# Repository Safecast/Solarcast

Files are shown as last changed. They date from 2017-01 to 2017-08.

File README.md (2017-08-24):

# Solarcast
Safecast Solarcast sensor device is designed to operate off-grid and sense environmental parameters. It consists of 5 key modules designed for maximal reuse.

## Modular design
 1. [Air sensor module](/air-module)
 2. [Geiger sensor module](/geiger-module)
 3. [Battery power module](/battery-module)
 4. [Communications module](/communications-module)
 5. [Gateway module](/gateway-module)

In an optimal design all modules have their own BLE processor and can be directly combined between each other, initial design is however only partially modular.

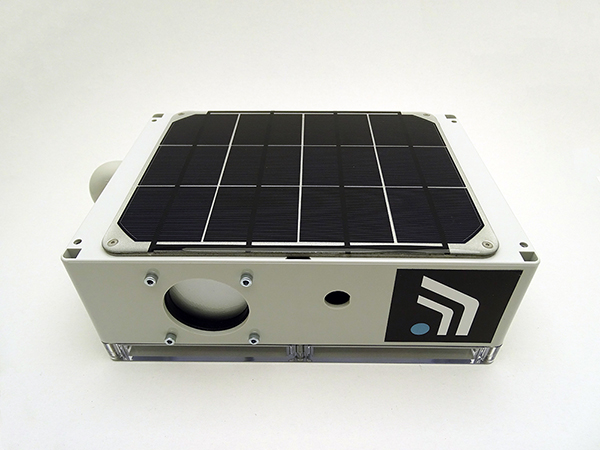
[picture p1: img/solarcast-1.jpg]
Solarcast-1

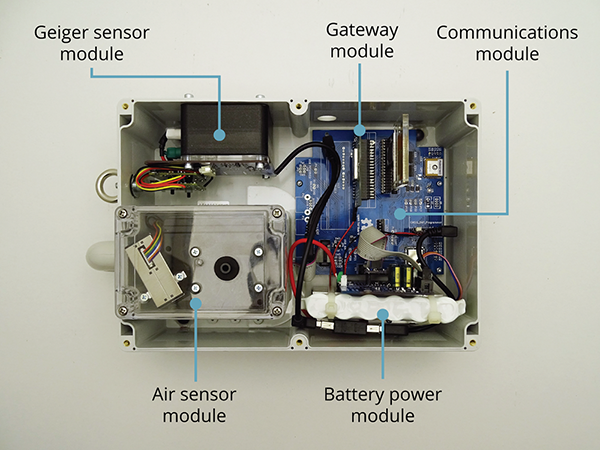
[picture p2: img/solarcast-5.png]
Solarcast-2


## Design parameters
The PCBs have to be designed in KiCad package.

---

#### License

Open data generated by Safecast is licensed under [CC0](https://creativecommons.org/publicdomain/zero/1.0/legalcode).

Hardware, Software, and Firmware licenses TBD.

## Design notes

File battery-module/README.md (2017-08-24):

### IoT power module description

This repository contains the design parameters and implementation details of the IoT battery pack originally developed for [Safecst Solarcast](https://github.com/IRNAS/Solarcast) sensor device.

## GENERAL DESCRIPTION

IoT power module is powered from single lithium-ion cells (2/4/6 cells in parallel) and provides 3V3 and 5V stabilized output as well as battery output. All inputs can be turned off to avoid power consumption, however by default 3V3 output is always active (see later). Both switcher chips are buck-boost topology and operate with very low current when idle (< 100 uA)

The module itself is equipped with switcher battery charger, where charging current can be externally programmed using resistors (R56, R58) or programming through I2C interface is also possible. An add-on module enables charging from external solar panel or other input, where integrated electronics adjusts the current in a way, that current is lowered when Uin_min threshold is achieved (currently at 4V5). Other option is charging through microUSB port with 5 VDC.

The module can be equipped with Nordic nRF51822 microprocessor (M0 with BLE), that can be used to monitor and control charging process. Additionally, fuel gauge MAX17201 chip is integrated, which can monitor all battery parameters such as voltage, current, temperature, calculates state-of-charge (SOC), state-of-health (SOH) and many other parameters.

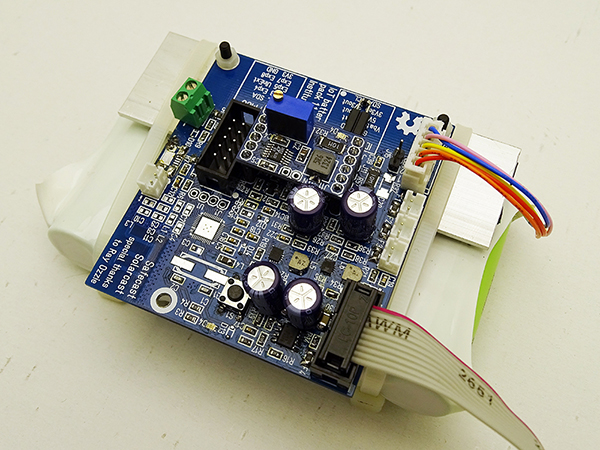
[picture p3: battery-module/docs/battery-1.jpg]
Battery-module


## BASIC BOARD OVERVIEW

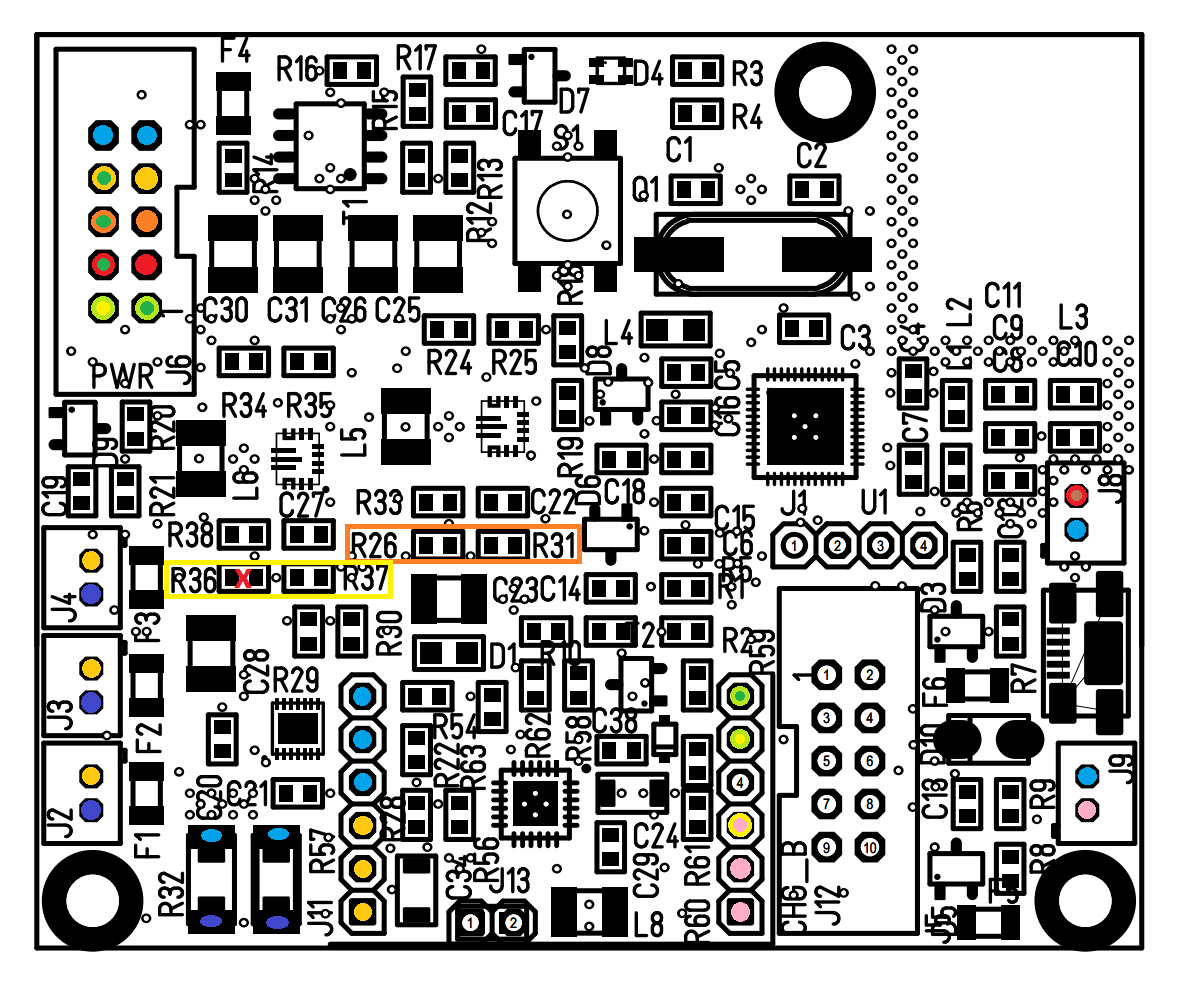
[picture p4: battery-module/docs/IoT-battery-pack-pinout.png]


### J2, J3, J4 (bottom left): Battery connectors, 3 pcs (JST 2-pole)
Connect to lithium battery pack. 3 packs can be connected simoultanously. Each branch is protected using 5A SMD fuse.
IMPORTANT!
 1. Always connect only battery packs with similar voltage/charging state. Connecting i.e. empty and full battery pack will drain huge current from full battery and burn fuse as well as damage to the batteries can be done!
 1. GND of the cells and GND of the system is not the same as there is a shunt resistor (R32, R57) in line between Cell_gnd and System_gnd.

### J6 (top left): PWR connector (IDC10):

diagram

1. - I2C SCL (3V3)
2. - I2C SDA (3V3)
3. - 5V0 output*
4. - 5V0_enable pin*
5. - 3V3 output (always on by default**)
6. - 3V3_enable pin (not used by default**)
7. - Vbat output (same logic as 5V0 output*)
8. - Vbat_enable pin
9. - GND
10. - GND

*By default, 5V0 output is disabled and can only be enabled if pulling 5V0 enable pin high. In case, that constant voltage is required on the 5V0 output, R36 must be populated. This will create resistor divider to define voltage level, when power will disable due to under-voltage condition.*

*By default, 3V3 output is always active and is disabled only, when under-voltage condition occurs (set to approx. 3V using R26 and R31). If you want to enable 3V3_enable control, R26 must be removed.*

### J8 + micro USB (middle right): +5 VDC power supply
Input for stabilized 5V power supply. Circuit around T2 serves adjusting charging current in a way, that if +5V power line drops, charging current is gradually reduced from approx. 1,8 A to 0,5 A at approx. 4,5 V.

### J9 (bottom right): external charging voltage (JST 2-pole)

Input for solar panel or other power source (voltage depends on a module installed).

### J11, J12 (bottom middle): connectors for add-on charging board

Module has prepared option to install add-on module with additional charger; this way i.e. MPPT module or wide-range DCDC charger can be installed and replaced if required. There are also I2C pins present at J12 as well as one additional pin from MCU as well as Usense pin, which regulates charging current for the on-board charging chip.

### J13 (bottom middle): connector for battery NTC thermistor (10k)

NTC thermistor must be thermally attached to the battery cell.

# IoT battery pack requirements
IoT battery pack is designed to provide power in various sensing applications, being able to deliver sufficient power for a wide range of sensors for short periods of time and have a long standby operation time between them. BLE interface allows users to configure it as well as provide a communication channel to talk to other sensors in the vicinity.

 * Capacity: 1P-6P Li-Po 18650 (3600mAh - 20000mAh)
  * Batteries connected in 3 branches of two, each branch fuse protected
  * User can connect 1-6 cells in parallel. For safety, no more then two can be directly connected in parallel, thus the 6 cells in parallel are split in 3 pairs of 2 cells in parallel, the sets connected together each via its own fuse.
  * Connector for cells: 2.54 JST (not mounted)
 * Input: 2A at 5V, input range 3-6V
  * DC jack input for solar cell, no diode used
  * Micro USB input for wall-socket (Additionally 2 pads for connections)
  * USB input must disconnect the solar cell and prevent discharge into it, can be done with a relay. Relay powered from USB socket via diode in a way, that NC is solar cell and NO is external 5 V input.
  * Current shall be adjustable from MCU (PWM?) and via trimmer in a way, that voltage is defined, where current is lowered (i.e. at 4V5 system goes to CV mode on input). Dynamic adjustment of charge current, such that the input voltage does not drop below 4.5V or other configurable level if possible. This prevents overloading of the supply, for example when solar cell is connected holds it reasonably close to maximum power output voltage. If possible the voltage level should be software controlled via BLE.

 * Output: 2A at 5V, 1A at 3.3V, direct battery voltage output
  * 5V - High-side switch or DC-DC module disable + fuse
  * 3.3V - High-side switch or DC-DC module disable + fuse
  * battery voltage - High-side switch and a fuse
  * Out connectors 2.54mm header/JST terminal
 * BLE processor (preferred Nordic nRF51822) on board implementing the following features in software:
  * battery voltage and current measurement. All voltages (inputs, outputs), current is measured through Fuel gauge chip via I2C
  * configurable thermal protection/shutdown via fuel gauge I2C
  * configurable battery charge voltage (over-voltage protection) via fuel gauge I2C
  * configurable battery discharge voltage (under-voltage protection) via fuel gauge I2C
  * I2C interface (nRF51822 SDA 10, SCL 8)
  * Enable/disable outputs as defined above
  * Expose remaining GPIO, about 8-10 are sufficient (to 10 pin header vcc/+3v3+8gpios)
  * RG(B) LED from MCU, software controlled and can be disabled fully
  * Standard Cortex programming connector
  * [Grove I2C connector](http://wiki.seeed.cc/Grove-I2C_Hub/)
 * Simultaneous charging and discharging
 * Low quiescent current - standby mode with 3.3V branch active no more then 100uA battery discharge current
 * Input DC-DC with current limiter
  * Dynamic adjustment of charge current, such that the input voltage does not drop below 4.5V or other configurable level if possible. This prevents overloading of the supply, for example when solar cell is connected holds it reasonably close to maximum power output voltage. If possible the voltage level should be software controlled via BLE.

 * Target production cost ~15EUR@1k
  * Batteries excluded
 * Prototyping process: 10 units for testing in first batch, 30 units in second batch

## Diagram
Diagram is made in http://draw.io

diagram

---

#### License

All our projects are as usefully open-source as possible.

Hardware including documentation is licensed under [CERN OHL v.1.2. license](http://www.ohwr.org/licenses/cern-ohl/v1.2)

Firmware and software originating from the project is licensed under [GNU GENERAL PUBLIC LICENSE v3](http://www.gnu.org/licenses/gpl-3.0.en.html).

Open data generated by our projects is licensed under [CC0](https://creativecommons.org/publicdomain/zero/1.0/legalcode).

All our websites and additional documentation are licensed under [Creative Commons Attribution-ShareAlike 4 .0 Unported License] (https://creativecommons.org/licenses/by-sa/4.0/legalcode).

What this means is that you can use hardware, firmware, software and documentation without paying a royalty and knowing that you'll be able to use your version forever. You are also free to make changes but if you share these changes then you have to do so on the same conditions that you enjoy.

Koruza, GoodEnoughCNC and IRNAS are all names and marks of Institut IRNAS Rače. 
You may use these names and terms only to attribute the appropriate entity as required by the Open Licences referred to above. You may not use them in any other way and in particular you may not use them to imply endorsement or authorization of any hardware that you design, make or sell.

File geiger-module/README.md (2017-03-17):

# Geiger module for Solarcast
Geiger module is a standalone sensor unit that is a part of the Solarcast assembly and houses two Geiger tubes and a temperature and humidity sensor along with an optional BLE processor module.

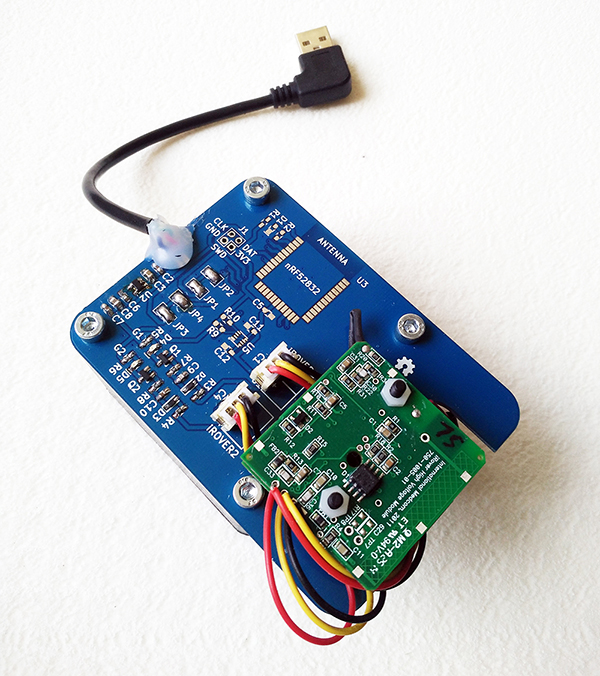
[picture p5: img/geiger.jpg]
Geiger


## Design specification
* BLE module NRF [nRF52832 ANT](https://www.tindie.com/products/hnhoan/nrf52832-ant-bluetooth-le-arm-cortex-m4f-30-io/)
* Geiger pancake sensor (may be a stack of two)
* Geiger gamma compensated tube sensor
* Temperature and humidity sensor BME280 sensor (I2C SDO high 0x77)
* 5V power supply via USB connector (no USB data)
* Outdoor enclosure [PNR-2603](http://eu.mouser.com/ProductDetail/Bud-Industries/PNR-2603/?qs=sGAEpiMZZMsrGrAVj6eTvTO11XxqWC53gJbMy7TDIp4%3d)
* BLE module LED-RED

## Extended details
* Waterproof [USB connector](http://eu.mouser.com/ProductDetail/Conxall-Switchcraft/DCP-USBCB-SC/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
) (data lines carry SWDIO & SWCLK signals or Geiger 1 and Geiger 2 output signals, configuration depending via jumper)
* Internal 3V3 regulator
* 2pcs iRover HV board, stacked

## Connection details
The devices have the following connection details:

*  nRF52832 module
 * Pin 3: P0.23	LED-RED
 * Pin 5: P0.25	TWI-SDA
 * Pin 6: P0.26 TWI-SCL
 * Pin 7: P0.28	GEIGER0
 * Pin 8: P0.29 GEIGER1
 * Pin 18: 3.3V
 * Pin 19: GND
 * Pin 21: SWCLK/TCK
 * Pin 22: SWDIO/TMS

## Board layout
The PCB board has the two tubes mounted on one side with cables passing though and being connected directly to iRover boards on the other side. These boards are placed one next to the other. BLE module is placed somewhere along the edge, USB connector is on the short edge opposite to the side where the cutout for cables is.

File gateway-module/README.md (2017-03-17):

# Gateway module for Solarcast
Gateway module implements LORA communication for two purposes, installing it inside the Solarcast device as a LORA communications module as well as attachign it to a RaspberryPi to act as a gateway.

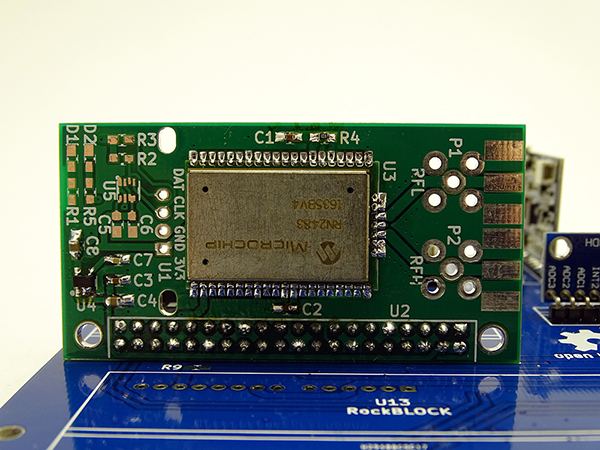
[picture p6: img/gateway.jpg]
Gateway


## Design specification
* LORA module [Microchip RN2483](http://www.microchip.com/wwwproducts/en/RN2483) for EU band, alternatively RN2903 for US band
* SMA connector for 434MHz (RF layout guide on [datasheet page 10](http://ww1.microchip.com/downloads/en/DeviceDoc/50002346B.pdf))
* SMA connector for 868MHz (RF layout guide on [datasheet page 10](http://ww1.microchip.com/downloads/en/DeviceDoc/50002346B.pdf))
* SSD1306 i2c display (optional)
* 5V power supply and an on board 3V3 regulator, such that it can eb used directly from 3V3 as well\
* Status LED for each RPi and LORA module
* Temperature and humidity sensor BME260 sensor (I2C SDO high 0x77)

## Connection details
The devices have the following connection details:

*  RN2483 module
 * Connect UART (RX,TX,RTS,CTS)
 * LED on GPIO
*  RaspberryPi
  * Connect UART (RX,TX,RTS,CTS)
  * Connect I2C
  * Connect an LED to GPIO

## Board layout
The PCB board is a RaspberryPi shield.

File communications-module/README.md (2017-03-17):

# Communications module for Solarcast
Communications module operates as the main module for the complete Solarcast assembly and is primarily a BLE device with other comms modules being plugged in.

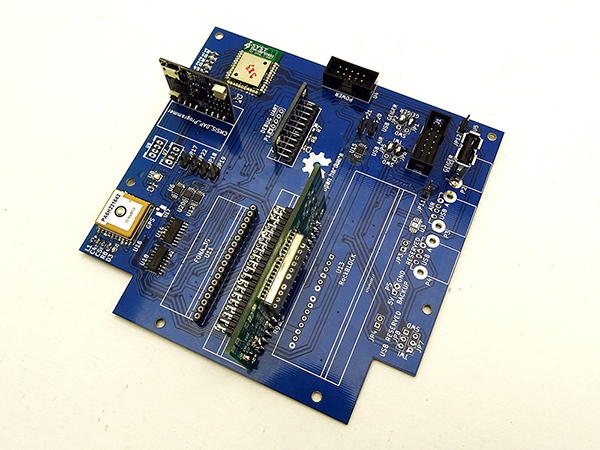
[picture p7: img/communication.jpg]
Communications-module


## Design specification
* NRF module [nRF52832 ANT](https://www.tindie.com/products/hnhoan/nrf52832-ant-bluetooth-le-arm-cortex-m4f-30-io/)
* Programmer [CMSIS-DAP](https://www.tindie.com/products/hnhoan/cmsis-dap-arm-debug-jtagswd-module-drag-and-drop/)
* [GPS module](https://www.adafruit.com/products/790)
* [Adafruit FONA 3G module](https://www.adafruit.com/products/2691) (Note version difference between USA and EU)
* GSM antenna [FXUB66.07.0150C](http://www.mouser.com/ProductDetail/Taoglas/FXUB66070150C/?qs=L8NdhHdZHXxzH3hw8Na69A%3D%3D)
* LORA antenna [FXUB66.01.0150C](http://www.mouser.com/ProductDetail/Taoglas/FXUB66010150C/?qs=sGAEpiMZZMuBTKBKvsBmlEt2wojY8dgW39nSVW3ZfN0%3d)
* BME280 sensor (SDO low 0x76)
* Add accelerometer [LIS3DSH](https://www.adafruit.com/products/2809) footprint for the ic and pins for breakout
* UART MUX SN74LV4052AD SOIC-16
* USB connector to outside world http://eu.mouser.com/ProductDetail/Conxall-Switchcraft/DCP-USBCB-SC/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
* Case: PN-1335
* Add a GPIO expansion port for later work (UART for Air can be on it and I2C and SPI)
* Three internal USB connectors, not carrying USB data
 * USB0 - data pins select between I2C and programming pins
 * USB1 - data pins select between I2C and programming pins
 * USB2 - data pins select between GEIGER0/GEIGER1 and programming pins
* Connector for power module
* 2 groove expansion ports
* External power switch mounted on the box.

## Power supply configuration
Solar operation of the device and minimal power consumption in the standby state govern the design requirements.

Power flow: Solar cell-> Power module (built-in regulators) -> Comms module -> Power switch and fan out to:
* Switch high-side 5V - USB0 for Air module - ENABLE-AIR - 250mA peak - [TPS2034D](http://www.ti.com/product/TPS2034D?keyMatch=TPS2034D&tisearch=Search-EN-Everything) regulated from battery pack
* Switch high-side 5V - USB1 for Geiger module - ENABLE-GEIG - 50mA peak - [TPS2034D](http://www.ti.com/product/TPS2034D?keyMatch=TPS2034D&tisearch=Search-EN-Everything) regulated from battery pack
* Switch high-side 5V - USB2 -reserve- 1A peak [TPS2034D](http://www.ti.com/product/TPS2034D?keyMatch=TPS2034D&tisearch=Search-EN-Everything)
* Switch high-side 5V - backup - 1A peak [TPS2034D](http://www.ti.com/product/TPS2034D?keyMatch=TPS2034D&tisearch=Search-EN-Everything)

Power switch disconnects power between power module and comms module.

Add headers for mosfet bypass for current consumption measurement and jumpers prior to voltage regulators.

## Board layout
The board is designed as a main board with all other modules connecting to it.

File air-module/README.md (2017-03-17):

# Air module for Solarcast
Air module is a standalone sensor unit that is a part of the Solarcast assembly and houses two particle sensors and a temperature and humidity sensor along with an optional BLE processor module.

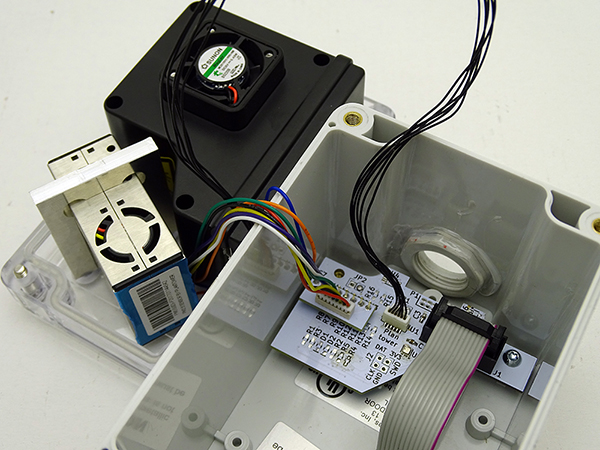
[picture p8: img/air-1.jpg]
Air-module


## Design specification
* BLE module NRF [nRF52832 ANT](https://www.tindie.com/products/hnhoan/nrf52832-ant-bluetooth-le-arm-cortex-m4f-30-io/)
* Particle sensor [Alphasense OPC-N2](http://www.alphasense.com/index.php/products/optical-particle-counter/) (SPI)
* Particle sensor [PM2.5 PMS 5003](http://www.plantower.com/en/content/?108.html) (UART)
* Temperature and humidity sensor BME280 sensor (I2C SDO high 0x77)
* 5V power supply via USB connector (no USB data)
* Outdoor enclosure [PNR-2603](http://eu.mouser.com/ProductDetail/Bud-Industries/PNR-2603/?qs=sGAEpiMZZMsrGrAVj6eTvTO11XxqWC53gJbMy7TDIp4%3d)
* Dual channel high side Switch high-side switch [TPS2034D](http://www.ti.com/product/TPS2034D?keyMatch=TPS2034D&tisearch=Search-EN-Everything) each output for one AIR sensor, with bypass header jumpers.

## Extended details
* Waterproof [USB connector](http://eu.mouser.com/ProductDetail/Conxall-Switchcraft/DCP-USBCB-SC/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
) (data lines carry SWDIO & SWCLK signals)
* Internal 3V3 regulator
* Expansion connector 2x6 (IDC connector) with SPI, I2C and UART

## Connection details
The devices have the following connection details:

* Alphasense (leftmost wire on connector with wire crimp contacts facing up going away from you) Connector: Molex 'Pico Clasp' 6 way Housing, Part Number 501330-0600
 1. 5V
 2. SPI-SCLK
 3. SPI-MISO
 4. SPI-MOSI
 5. SPI-CS
 6. GND

* Plantower, no connector, solder wires
  1. 5V
  2. GND
  3. N/C
  4. RX (optional SCL) (add 0 ohm resistors to select between uart and i2c pins)
  5. TX (optional SDA) (add 0 ohm resistors to select between uart and i2c pins)
  6. N/C
  7. comm config (add solder jumpers for pull up/down)
  8. comm config (add solder jumpers for pull up/down)

*  nRF52832 module
 * Pin 3: P0.23	LED-RED
 * Pin 5: P0.25	TWI-SDA
 * Pin 6: P0.26 TWI-SCL
 * Pin 7: P0.27 UMUX-INH
 * Pin 18: 3.3V
 * Pin 19: GND
 * Pin 20: P0.07 TX
 * Pin 21: SWCLK/TCK
 * Pin 22: SWDIO/TMS
 * Pin 23: P0.08 RX
 * Pin 28: P0.03 SPI-MOSI
 * Pin 29: P0.04 SPI-MISO
 * Pin 30: P0.05 SPI-CS
 * Pin 31: P0.06 SPI-SCLK

 ## Board layout
 The PCB board has a connector of each particle sensor, BLE module on the short board edge and the USB connector on the edge between two rounded corners.

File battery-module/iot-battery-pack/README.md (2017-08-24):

# IoT battery pack hardware
Last revision is v.1.2 available in this repository, while v.1.1 version can with manual fixes be brought to v.1.2.

## IoT power supply errata HW REV affected: v.1.1

- Missing 10 uF 10V X7R 0805 capacitors at input and output of IC1 and IC2 (fixed at v.1.2)
- Check/enlarge track for VBAT to BAT FET, optimize vias (too much current drop) (fixed at v.1.2)
- Modify resistor divider on MPPT charger to set charging voltage to 4,10 V (4,0 at v.1.1)

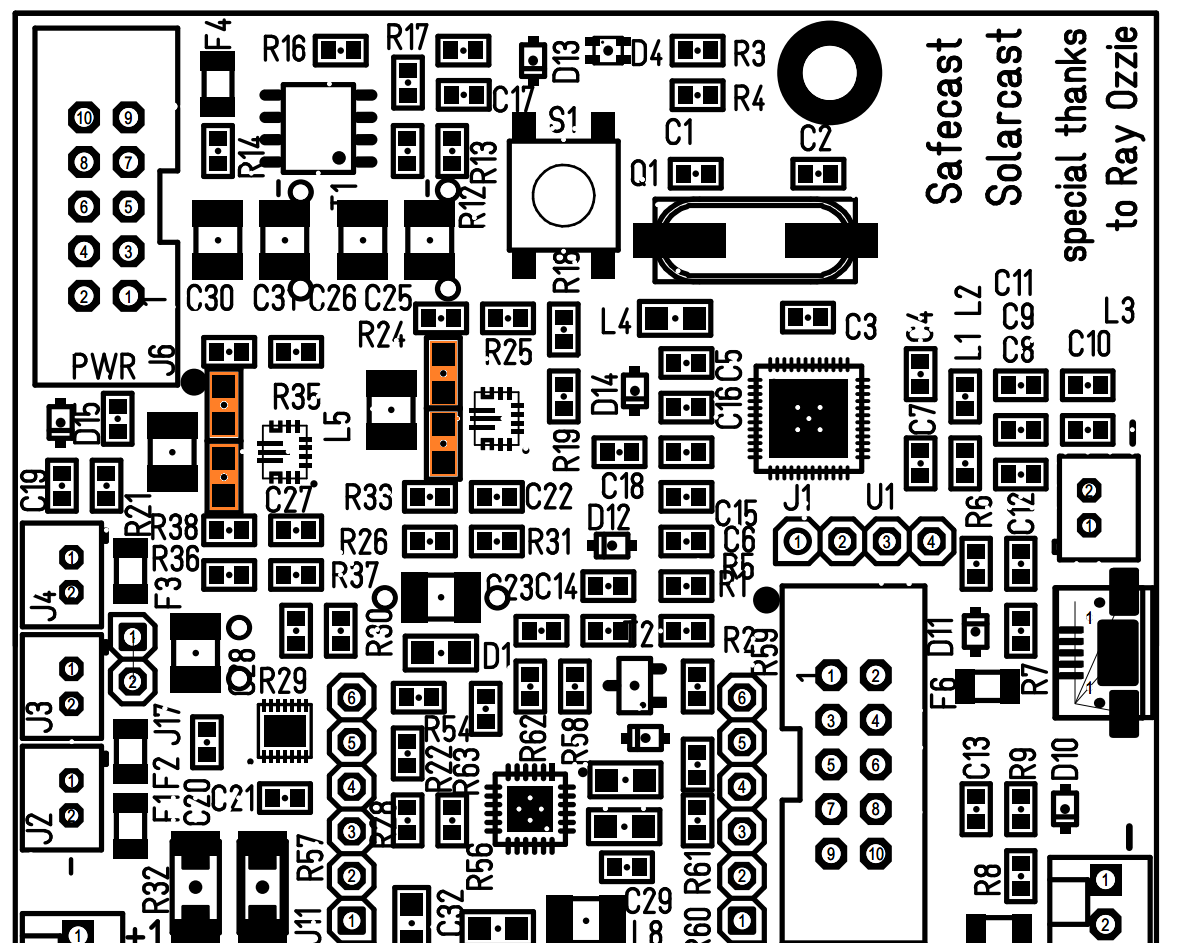
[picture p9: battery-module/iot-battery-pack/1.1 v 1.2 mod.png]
diagram


## Fuses
 * F1 - Battery fuse 3A
 * F2 - Battery fuse 3A
 * F3 - Battery fuse 3A
 * F4 - Battery output fuse 3A
 * F5 - Solar input fuse 3A
 * F6 - USB input fuse 3A

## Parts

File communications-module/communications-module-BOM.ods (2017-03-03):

Designator | Package | Quantity | Description | Supplier Link
C1,C2,C3,C5 | 0603_HandSoldering | 4 | 100nF
C4 | 0603_HandSoldering | 1 | 1uF
D1,D2,D3 | LED_0603_HandSoldering | 3 | LED
J1 | IDC12_connector | 1 | IDC12
JP3,JP4,JP11,JP12,JP17,JP18,JP19,JP20,JP21,JP22 | Socket_Strip_Straight_1x02_Pitch2.54mm | 10 | Jumper2
L1 | 0603_HandSoldering | 1 | Ferrite bead | http://si.farnell.com/murata/blm18ag221sn1d/ferrite-bead-0-25ohm-500ma-0603/dp/1515674
P2,P3,P4 | USB_A_receptacle | 3 | USB_A | http://si.farnell.com/te-connectivity-amp/292303-1/usb-2-0-type-a-plug-cable/dp/1076663
P5 | Socket_Strip_Straight_1x02_Pitch2.54mm | 1 | BACKUP
R1,R2,R8 | 0603_HandSoldering | 3 | 1K
R3,R4,R5,R9 | 0603_HandSoldering | 4 | 10K
R6,R7 | 0603_HandSoldering | 2 | 0R
U1 | nRF52832-SMD | 1 | nRF52832 | https://www.tindie.com/products/hnhoan/nrf52832-ant-bluetooth-le-arm-cortex-m4f-30-io/
U2 | CMSIS_DAP_Breakout_Vertical | 1 | CMSIS_DAP_Programmer | https://www.seeedstudio.com/Seeed-Tiny-BLE-BLE-%2B-6DOF-Mbed-Platform-p-2268.html
U3,U5,U6,U12,U15,U20 | 8-Pin MSOP | 6 | TPS2066 | http://si.farnell.com/texas-instruments/tps2066dgn/power-load-switch-high-side-msop/dp/2323772
U4 | IDC10_connector | 1 | PWR_CONN
U7,U9 | Seeed Studio DIP Grove 4P-2_0 | 2 | I2C_connector | https://www.seeedstudio.com/Grove---Universal-4-pin-connector-p-789.html
U8 | 8-Pin LGA | 1 | BME280 | http://eu.mouser.com/ProductDetail/Bosch-Sensortec/BME280/
U10 | LIS3DH_breakout_vertical | 1 | LIS3DH_breakout | http://www.dx.com/p/cjmcu-lis3dh-3-axis-acceleration-module-alternative-adxl345-441837#.WKMPqfLwT2Y
U11 | FONA_3G_vertical | 1 | FONA_3G | https://learn.adafruit.com/adafruit-fona-3g-cellular-gps-breakout/overview
U13 | RockBlock_vertical | 1 | RockBLOCK | http://www.rock7mobile.com/products-rockblock
U14,U18 | SOIC-16 | 2 | SN74LV4052AD | http://si.farnell.com/texas-instruments/sn74lv4052ad/logic-mux-demux-4ch-analog-16soic/dp/1740190?aa=true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
U16 | FGPMMOPA6H | 1 | FGPMMOPA6H GPS | https://www.adafruit.com/product/790
U17 | U.FL-R-SMT | 1 | uFL_connector | http://si.farnell.com/hirose-hrs/u-fl-r-smt-1-10/rf-coaxial-u-fl-straight-jack/dp/1688077
U19 | Solarcast_Gateway_Module_Vertical | 1 | Gateway Module LORA
JP1,JP2,JP5,JP6,JP7,JP8 | Socket_Strip_Straight_1x03_Pitch2.54mm | 6 | Jumper3

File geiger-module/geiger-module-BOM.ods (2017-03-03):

Designator | Package | Quantity | Description | Supplier Link
J1 | Socket_Strip_Straight_2x02 | 1 | ARM_SWD_SMALL
U5 | 8-Pin LGA | 1 | BME280 | http://www.digikey.si/product-detail/en/bosch-sensortec/BME280/828-1063-1-ND/6136314
U4,U1 | JST B3B-PH-SM4-TB | 2 | iRover | http://si.farnell.com/jst-japan-solderless-terminals/b3b-ph-sm4-tb-lf-sn/connector-header-smt-2mm-3way/dp/9492542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
U3 | nRF52832-SMD | 1 | nRF52832 | https://www.tindie.com/products/hnhoan/nrf52832-ant-bluetooth-le-arm-cortex-m4f-30-io/
U2 | 5-Pin SOT23 | 1 | TPS79133 | http://si.farnell.com/texas-instruments/tps79133dbvt/ic-v-reg-ldo-0-1a-3-3v-smd-79133/dp/8461767
R10,R9,R1 | 0603_HandSoldering | 3 | 10K
R8,R7 | 0603_HandSoldering | 2 | 100K
R6,R5,R2 | 0603_HandSoldering | 3 | 100R
R4,R3 | 0603_HandSoldering | 2 | 1K
Q2,Q1 | 3-Pin SOT23 | 2 | BC847C | http://si.farnell.com/infineon/bc-847c-e6327/transistor-bipol-npn-45v-sot-23/dp/2432696
P1 | DCP-USBCB-SC | 1 | USB_OTG | http://eu.mouser.com/ProductDetail/Conxall-Switchcraft/DCP-USBCB-SC/
JP4,JP3,JP2,JP1 | Socket_Strip_Straight_1x02 | 4 | JUMPER
D5,D4,D1 | LED_0603_HandSoldering | 3 | LED
D3,D2 | SOD-323 | 2 | 1N4148 | http://si.farnell.com/multicomp/1n4148ws/diode-h-speed-100v-0-15a-sod323/dp/1466524
C12,C11,C10,C9,C7,C5,C4,C2,C1 | 0603_HandSoldering | 9 | 100nF
C6 | 0603_HandSoldering | 1 | 10nF
C3,C8 | 0805_HandSoldering | 2 | 10uF

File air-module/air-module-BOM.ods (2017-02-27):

Designator | Package | Quantity | Description | Supplier Link
U6 | 5-Pin SOT23 | 1 | TPS79133 | http://si.farnell.com/texas-instruments/tps79133dbvt/ic-v-reg-ldo-0-1a-3-3v-smd-79133/dp/8461767
U5 | 8-Pin LGA | 1 | BME280 | http://eu.mouser.com/ProductDetail/Bosch-Sensortec/BME280/
U4 | 8-Pin MSOP PowerPAD | 1 | TPS2064 | http://si.farnell.com/texas-instruments/tps2064cdgnr-2/load-switch-dual-5-5v-1a-8msop/dp/2307999
U3 | Socket_Strip_Straight_1x08 2.45mm | 1 | Plantower_PM2.5_PMS_5003 | http://aqicn.org/sensor/pms5003-7003/
U1 | Molex_501331-0607 | 1 | Alphasense_OPC-N2 | http://www.alphasense.com/index.php/products/optical-particle-counter/ ; http://si.farnell.com/molex/501331-0607/header-1-0mm-pico-clasp-6way/dp/1835980
R16,R15,R5,R4,R1 | 0603_HandSoldering | 5 | 10K
R14,R13,R12,R11,R10,R9,R8,R7 | 0603_HandSoldering | 8 | 0R
R3,R2 | 0603_HandSoldering | 2 | 1K
JP2,JP1 | Socket_Strip_Straight_1x02 2.45mm | 2 | JUMPER
J1 | IDC12_connector | 1 | IDC12
D2,D1 | LED_0603_HandSoldering | 2 | LED
C10,C8,C7,C5 | 0805_HandSoldering | 4 | 10uF
C9,C6,C3,C2,C1 | 0603_HandSoldering | 5 | 100nF
C11 | 0603_HandSoldering | 1 | 10nF
J2 | Socket_Strip_Straight_2x02 2.45mm | 1 | ARM_SWD_SMALL
P1 | DCP-USBCB-SC | 1 | USB_OTG | http://eu.mouser.com/ProductDetail/Conxall-Switchcraft/DCP-USBCB-SC/
U2 | nRF52832-SMD | 1 | nRF52832 | https://www.tindie.com/products/hnhoan/nrf52832-ant-bluetooth-le-arm-cortex-m4f-30-io/
P2 | Molex-53047-0810 | 1 | Plantower_PM2.5_PMS_5003 | http://si.farnell.com/molex/53047-0810/header-vertical-8way/dp/1012258?ost=Molex-53047-0810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

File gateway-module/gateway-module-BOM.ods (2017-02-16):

Designator | Package | Quantity | Description | Supplier Link
U2 | Socket_Strip_Straight_2x20 2.45mm | 1 | RaspberryPi
C1,C2,C3,C5,C6 | 0603_HandSoldering | 5 | 100nF
C4,C8 | 0805_HandSoldering | 2 | 10uF
C7 | 0603_HandSoldering | 1 | 10nF
D1,D2 | LED_0603_HandSoldering | 2 | LED
R1,R5 | 0603_HandSoldering | 2 | 1K
R2,R3,R4 | 0603_HandSoldering | 3 | 10K
U3 | RN2483 | 1 | RN2483 | http://eu.mouser.com/ProductDetail/Microchip-Technology/RN2483-I-RM101/
U4 | 5-Pin SOT23 | 1 | TPS79133 | http://si.farnell.com/texas-instruments/tps79133dbvt/ic-v-reg-ldo-0-1a-3-3v-smd-79133/dp/8461767
U5 | 8-Pin LGA | 1 | BME280 | http://www.digikey.si/product-detail/en/bosch-sensortec/BME280/828-1063-1-ND/6136314
U1 | Small_I2C_OLED | 1 | small_i2c_oled | https://www.amazon.com/Diymall%C2%AE-Yellow-Serial-Arduino-Display/dp/B00O2LLT30 (https://www.amazon.com/Diymall®-Yellow-Serial-Arduino-Display/dp/B00O2LLT30)
P2,P1 | SMA_coax | 2 | SMA | http://si.farnell.com/johnson/142-0701-801/rf-coaxial-sma-straight-jack-50ohm/dp/1608592?ost=142-0701-801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
C1,C2,C3,C5,C6 | 0603_HandSoldering | 5 | 100nF
C4,C8 | 0805_HandSoldering | 2 | 10uF

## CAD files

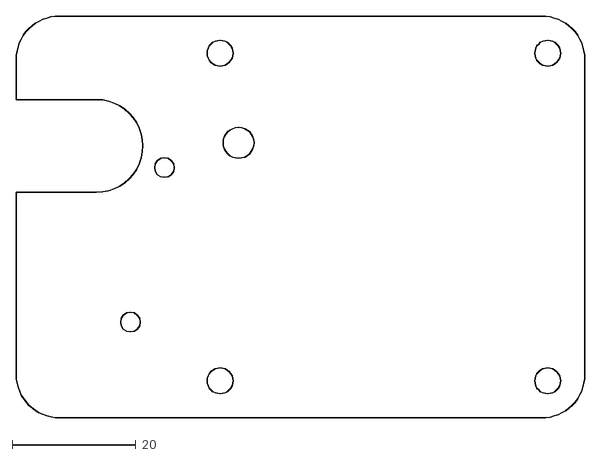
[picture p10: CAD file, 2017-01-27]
geiger-module/Geiger pcb - Face.dxf
92.0 x 65.0

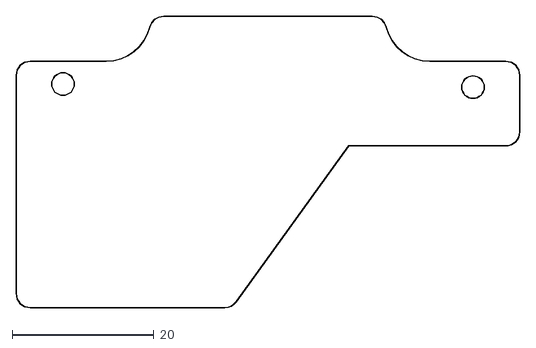
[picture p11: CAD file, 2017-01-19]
air-module/Part Studio 1 - Face.dxf
71.1 x 41.1

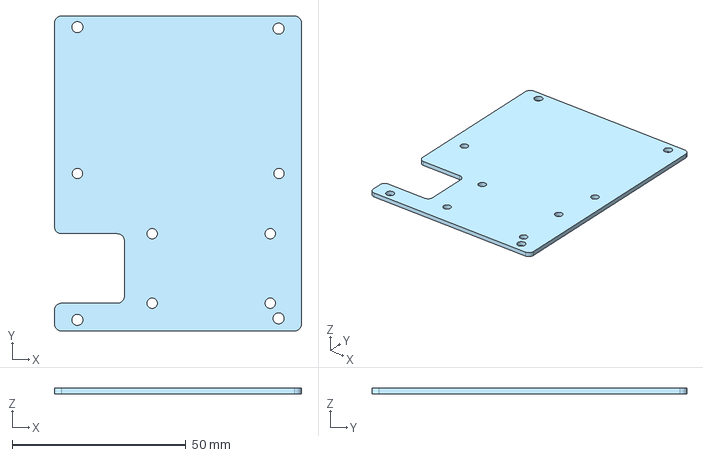
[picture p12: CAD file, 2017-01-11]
geiger-module/Solarcast-Geiger-PCB.step
71.1 x 90.7 x 1.60 mm

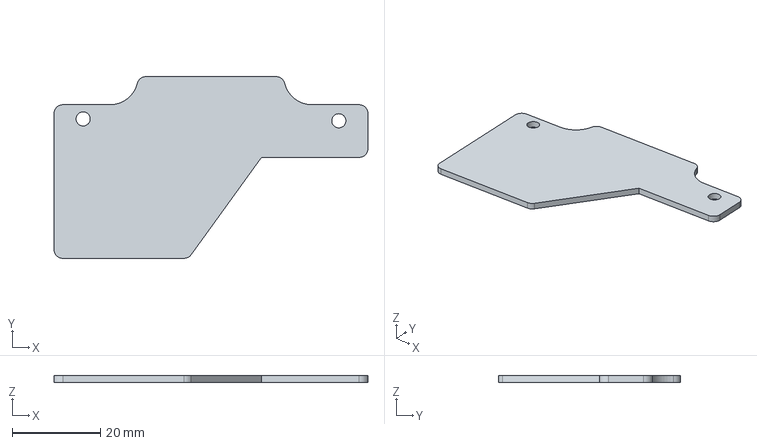
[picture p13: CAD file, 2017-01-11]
air-module/Solarcast-Air-PCB.step
71.1 x 41.1 x 1.60 mm

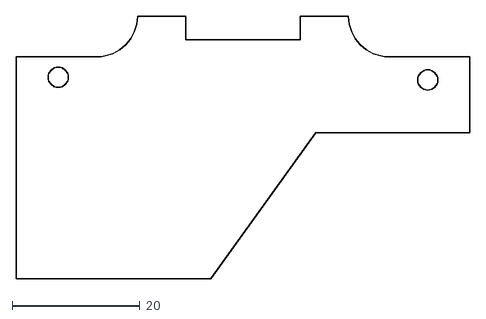
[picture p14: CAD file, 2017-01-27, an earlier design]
air-module/Part Studio 1 - Face(2).dxf
71.1 x 41.1

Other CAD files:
air-module/Solarcast-Air-PCB.dxf

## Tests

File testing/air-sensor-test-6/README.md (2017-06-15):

## Outdoor Air Sensor test - 22 unit analysis

This test was the first try to evaluate long term performance in an outdoor environment. The units were stacked in an open backyard garden and were exposed to all environmental influences day and night for two and a half days.

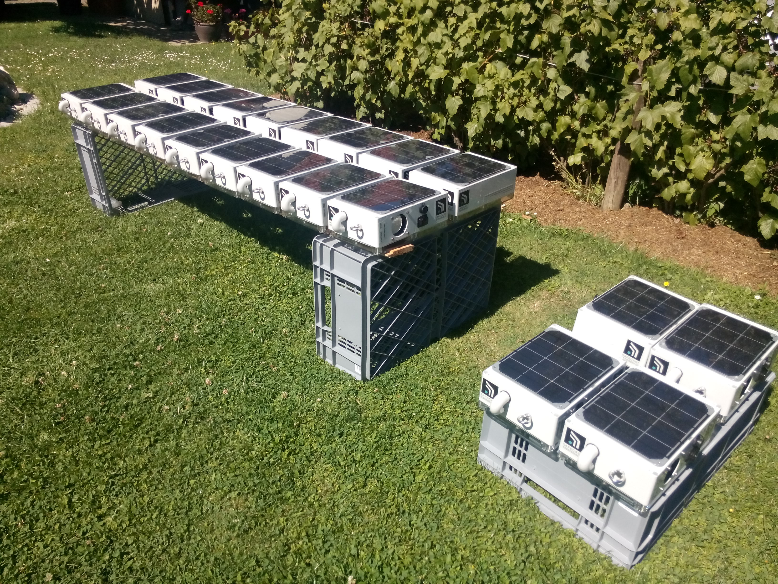
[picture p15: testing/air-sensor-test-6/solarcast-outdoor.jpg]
outdoor units


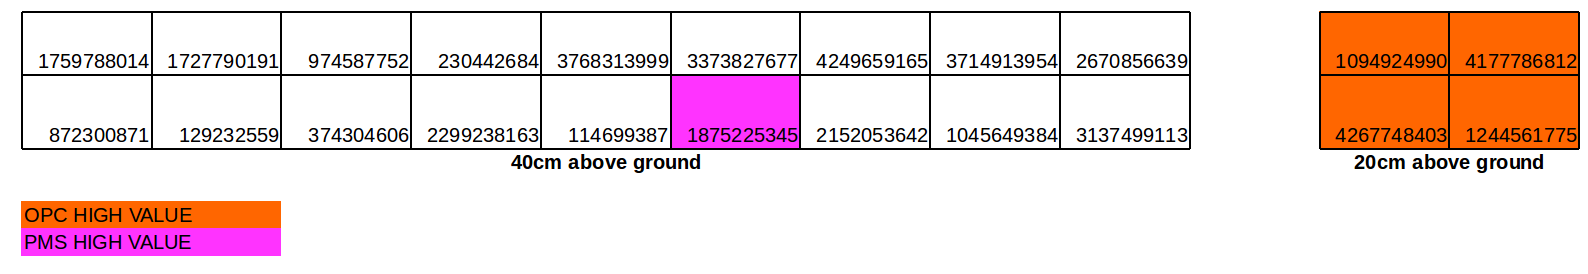
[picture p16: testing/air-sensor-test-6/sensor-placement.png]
outdoor placement


The following units have suggested fixes and checks:

Replacement of air sensor:
 * 1875225345 (too high readings) - replace PMS

Note that the 4 offending OPC units are placed closer to the ground
 * 4267748403 (too high readings)  - replace OPC, PMS
 * 1244561775 (too high readings) - replace OPC
 * 4177786812 (too high readings)  - replace OPC
 * 1094924990 (too high readings) - replace OPC
 
 THe following unit has a problem with BME0 sensor that must be replaced.
 * 3768313999 (crashing due to OPC/BME0, likely a SW bug of floating-point) 
 
Replacement of antenna:
 * 114699387 - done

## Battery status
The following graphs show battery charge percentage (%), current (mA) and voltage results (V) on units of time in hours. We can see a reasonably similar discharge on all units but two, that require servicing. Note that charge percentage varies due to missing software calibration of the fuel gauge.

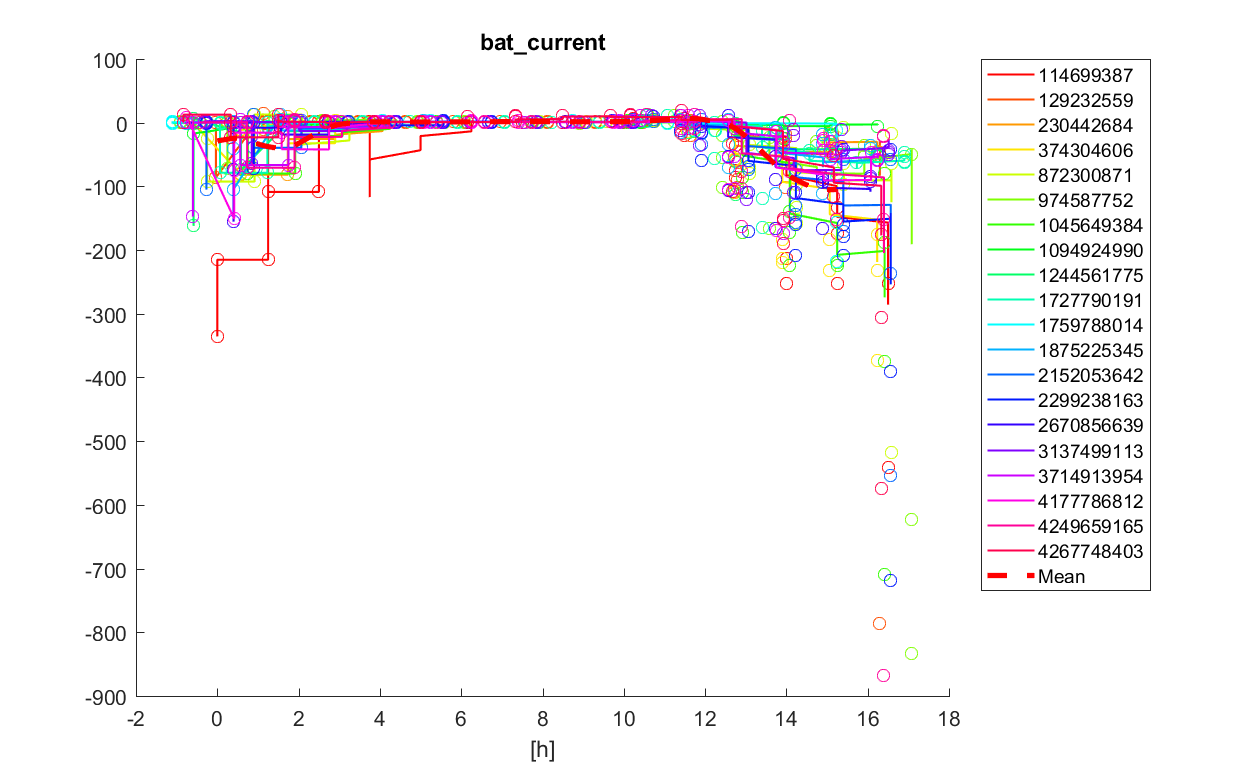
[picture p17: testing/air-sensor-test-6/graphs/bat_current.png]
bat_current


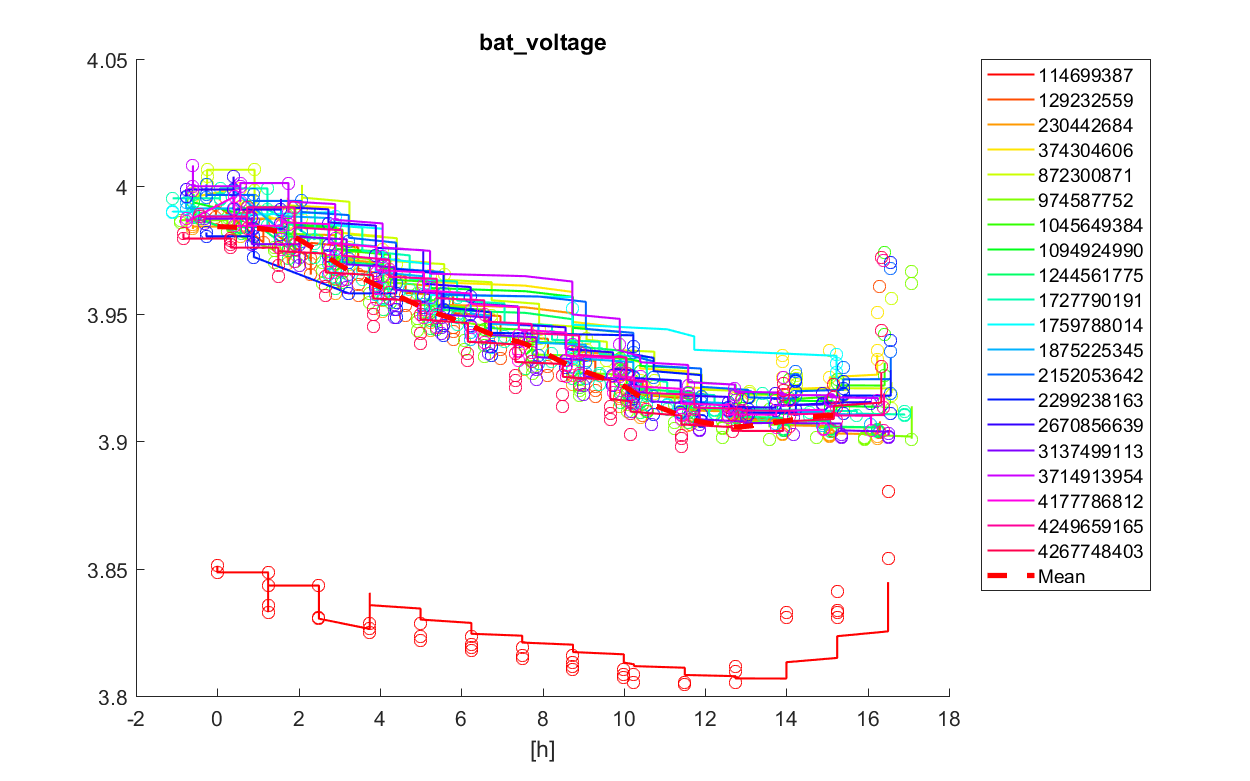
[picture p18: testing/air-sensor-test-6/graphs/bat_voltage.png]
bat_voltage


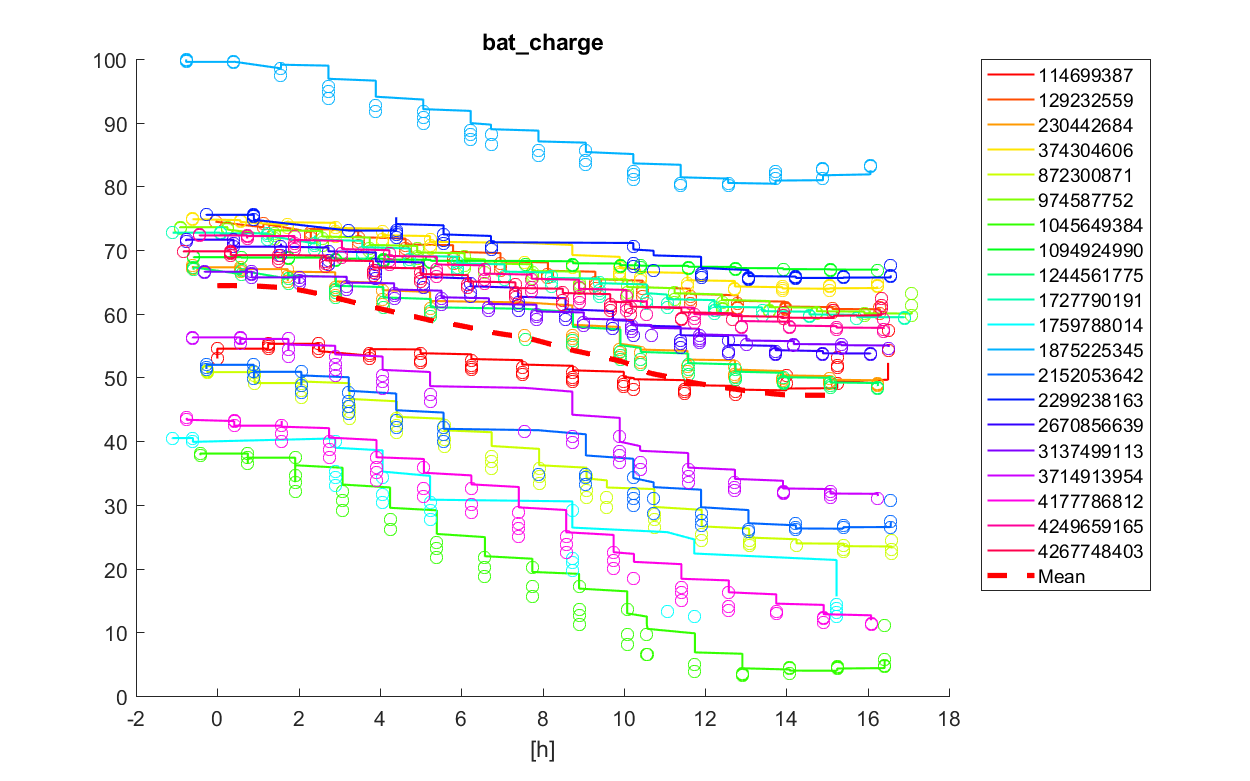
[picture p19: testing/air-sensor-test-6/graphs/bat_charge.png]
bat_charge


## Pressure, temperature and humidity
The following graphs show relative humidity (%), pressure (mbar) and temperature (deg C). We can observe daily variation in humidity and temperature, which is reasonably coherent on all units but two, that were supposedly off-line for some time periods.    

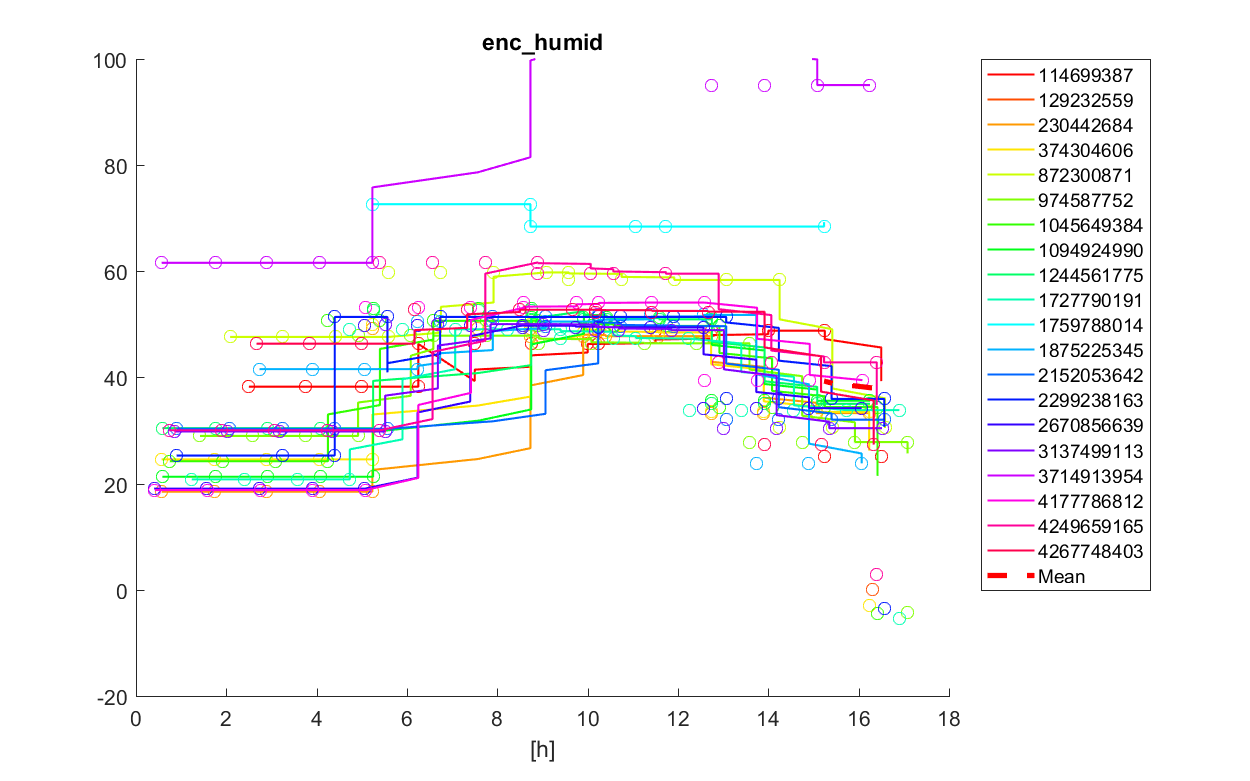
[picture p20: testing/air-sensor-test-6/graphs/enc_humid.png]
enc_humid


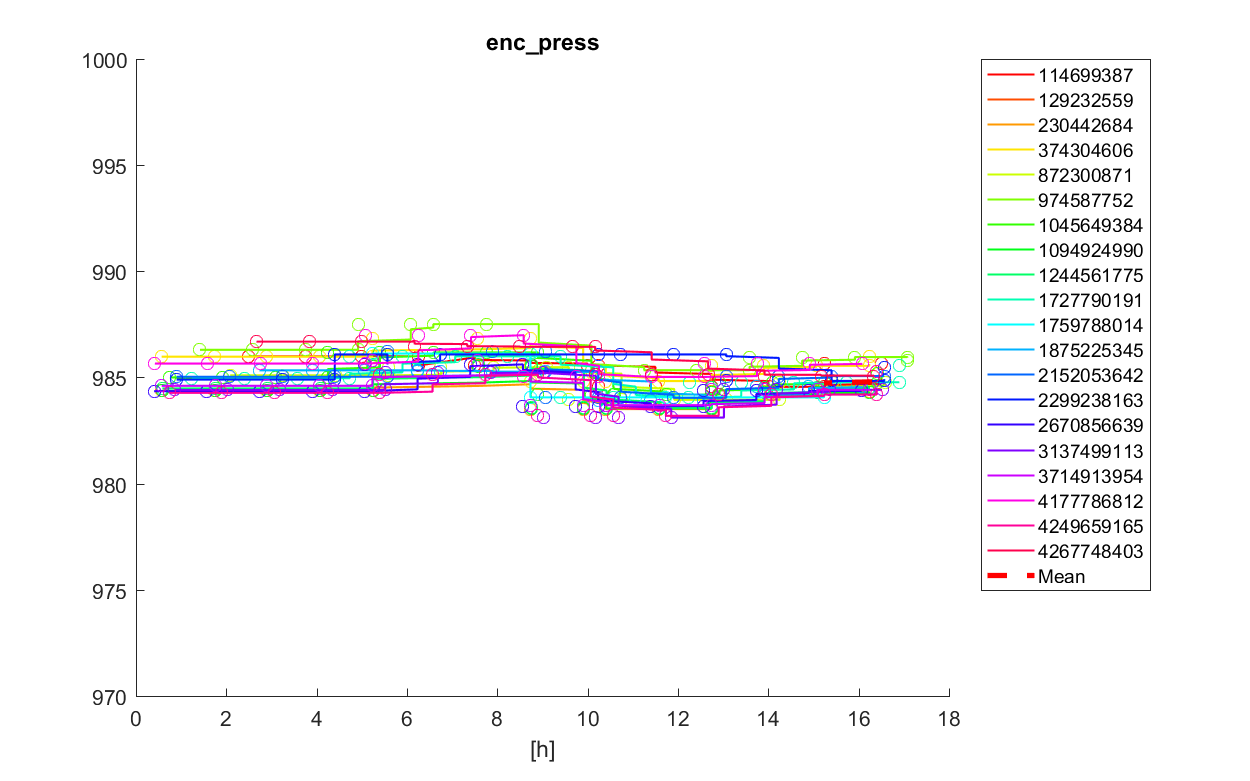
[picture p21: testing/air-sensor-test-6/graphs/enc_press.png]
enc_press


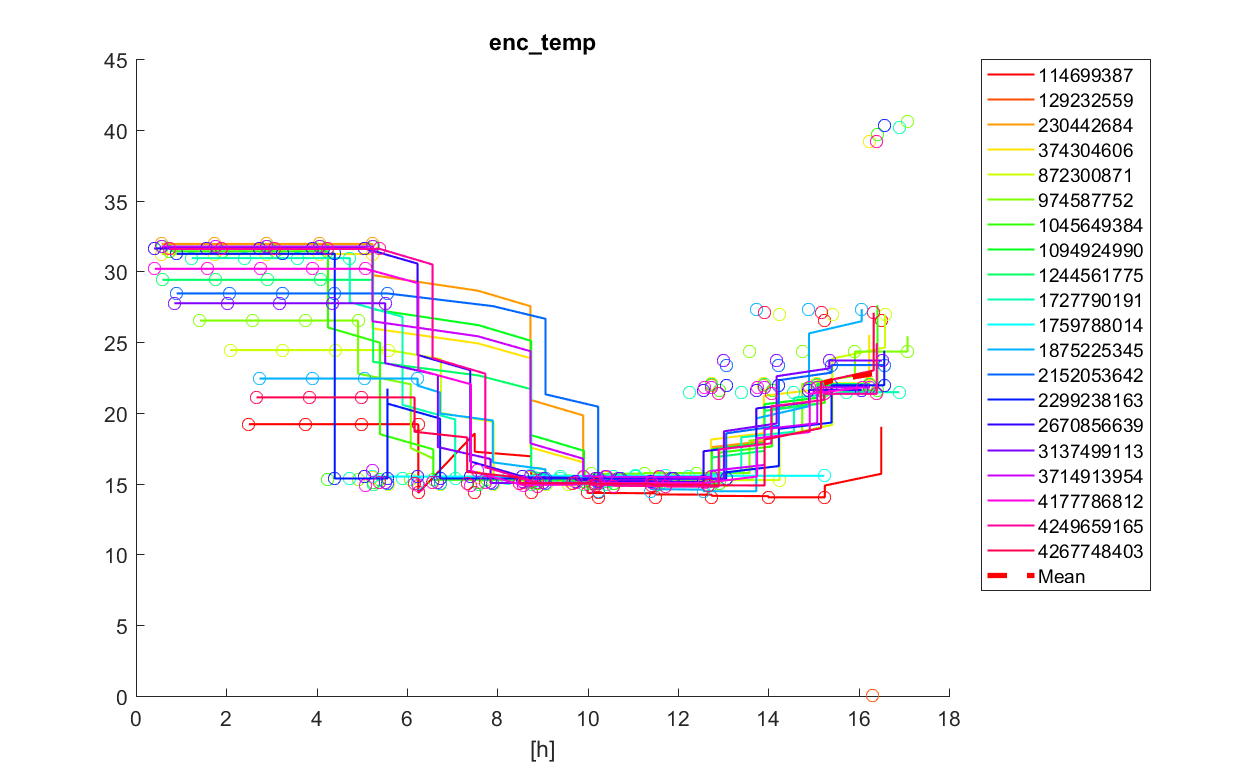
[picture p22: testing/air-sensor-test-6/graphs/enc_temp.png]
enc_temp


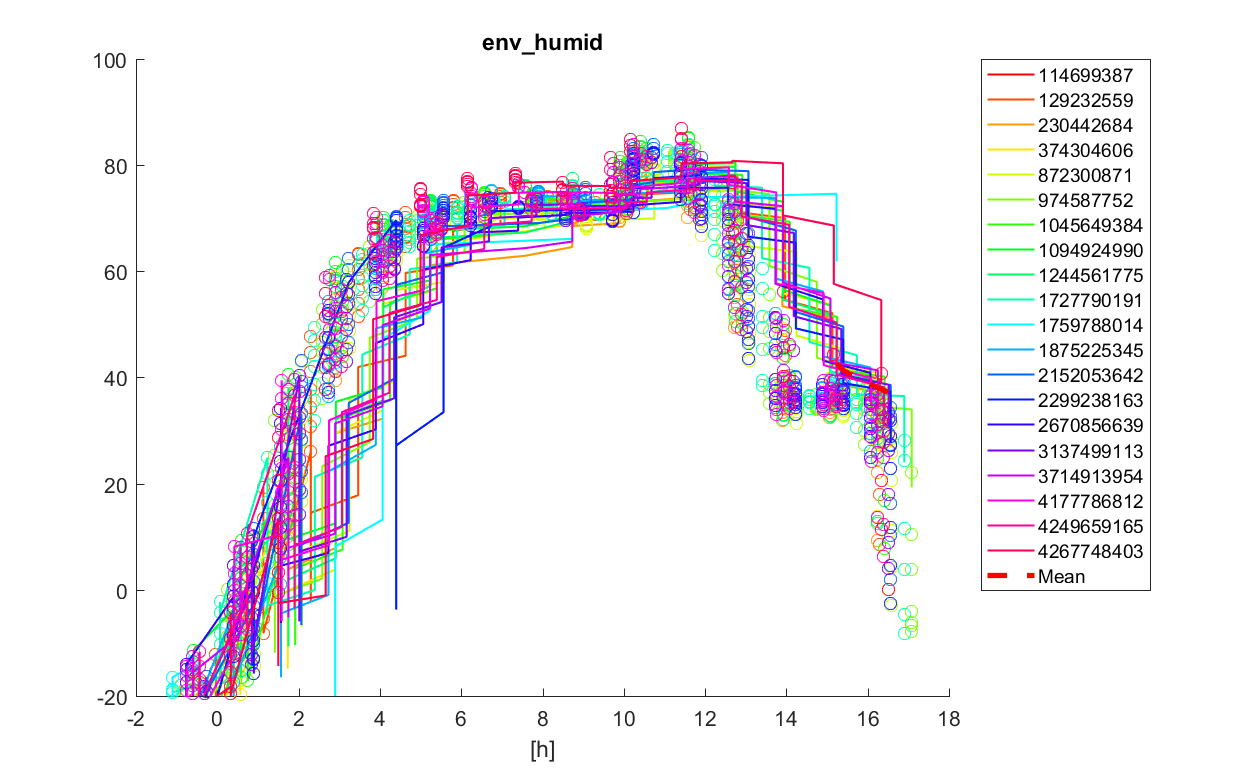
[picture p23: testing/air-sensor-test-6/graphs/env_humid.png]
env_humid


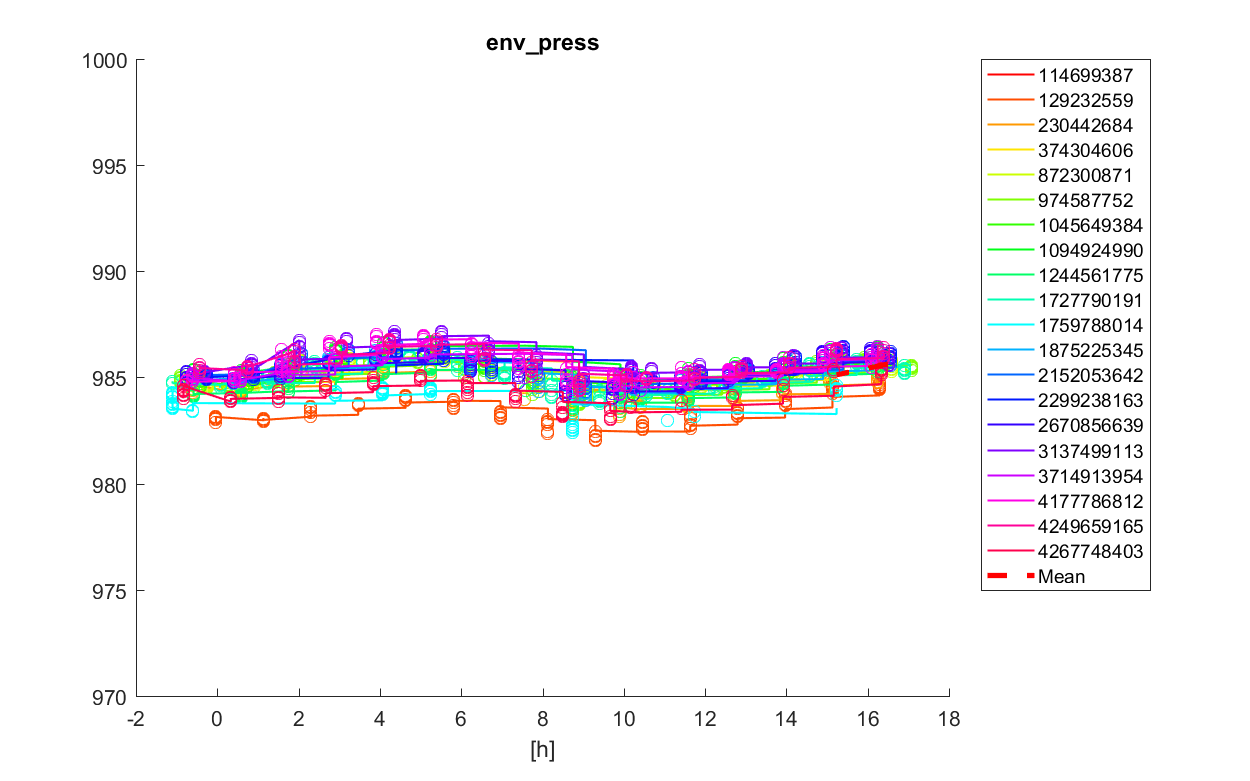
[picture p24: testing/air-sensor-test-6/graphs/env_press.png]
env_press


env_temp

## Radiation
Radiation measurements are observed for any significant out of range values. Most of the time we observe only the background radiation with a rather random pattern between units, apart for one significant increase at approximate 20h after start of the experiment, coinciding with picnic activity nearby units.  

lnd_7318c

lnd_7318u

## OPC Air sensor PM values
Alpnasense OPC-N2 sensors return values of PM1, PM2.5 and PM10 counts in ug/m3 concentration. We can see spikes during different times for different particle sizes. We observe a reasonably similar measurements on all units but one, represented by a blue line, where sensor presumably stopped working. In two more units, periods without measurements can be observed as well. 

opc_pm01_0

opc_pm02_5

opc_pm10_0

## PMS Air sensor PM values
APMS sensors returns values of PM1, PM2.5 and PM10 counts in ug/m3 concentration. We observe that PMS sensors measure concentration in more discrete levels and generally agree with OPC measurements. Only two units did record slightly outstanding values of all PM particles trough the experiment. Values of light blue unit were constantly higher and those of the dark orage unit constantly lowest than the average. 

pms_pm01_0

pms_pm02_5

pms_pm10_0

## OPC Air sensor raw bin count values
These raw bin count values are graphed for convenience of analysis.

opc_c00_38

opc_c00_54

opc_c01_00

opc_c02_10

opc_c05_00

opc_c10_00

## PMS Air sensor raw bin count values
These raw bin count values are graphed for convenience of analysis.

pms_c00_30

pms_c00_50

pms_c01_00

pms_c02_50

pms_c05_00

pms_c10_00

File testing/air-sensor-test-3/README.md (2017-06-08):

## Air Sensor test - 19 unit analysis

This test was the first try to evaluate performance in a dusty environment, which rather failed but produced some interesting results, see below for details.

setup

The units were stacked in the machine workshop with a large vacuum pump running between 0 and 4 hours period on these graphs and lifting lots of dust in the air.

Timeline:
 * 0-4h - pump running and dust circulating
 * around 4h - additional dust added to the pump to disperse
 * around 4h - pump turned off
 * after 4h - pump turned off and space closed without any movement for settling period.

One unit was mis-behaving during the experient, with pink colored data.

## Battery status
The following graphs show battery charge percentage (%), current (mA) and voltage results (V) on units of time in hours. We can see a reasonably similar discharge on all units but one, that requires servicing.

bat_charge

bat_current

bat_voltage

## Pressure, temperature and humidity
The following graphs show relative humidity (%), pressure (mbar) and temperature (deg C). We can observe that during the first part of the experiment when teh fan was running, humidity measurements are significantly different between units, but later stabilize in steady air.

enc_humid

enc_press

enc_temp

env_humid

env_press

env_temp

## Radiation
Radiation measurements are observed for any significant out of range values, we observe only the background radiation with a rather random pattern between units, ranging between 25 and 33 cpm for the compensated tube and 23 to 36 cpm for uncompensated.

lnd_7318c

lnd_7318u

## OPC Air sensor PM values
Alpnasense OPC-N2 sensors return values of PM1, PM2.5 and PM10 counts in ug/m3 concentration. We can see spikes during different times for different particle sizes, somewhat correlated to human intervention and introducing some extra dust around the 4 hour mark

opc_pm01_0

opc_pm02_5

opc_pm10_0

## PMS Air sensor PM values
APMS sensors returns values of PM1, PM2.5 and PM10 counts in ug/m3 concentration. We observe that PMS sensors measure concentration in more discrete levels and genrally agree with OPC measurements, except around the 4 hour mark, when there was a high increase in large particles, recognized by OPC, but that significantly PMS.

pms_pm01_0

pms_pm02_5

pms_pm10_0

## OPC Air sensor raw bin count values
These raw bin count values are graphed for convenience of analysis.

opc_c00_38

opc_c00_54

opc_c01_00

opc_c02_10

opc_c05_00

opc_c10_00

## PMS Air sensor raw bin count values
These raw bin count values are graphed for convenience of analysis.

pms_c00_30

pms_c00_50

pms_c01_00

pms_c02_50

pms_c05_00

pms_c10_00

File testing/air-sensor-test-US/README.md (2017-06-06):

## Air Sensor test - 3 unit analysis

Devices as a part of this experiment:
- 1238569003
- 1660294046
- 3709008148

## Battery status
The following graphs show battery charge percentage (%), current (mA) and voltage results (V) on units of time in hours. . We can observe that on normal days units will cycle between 3.9 and 4V. note that Charge percentage is the best calue to look at untill the Fuel gauge IC is configured/trained correctly for the cells.

bat_charge

bat_current

bat_voltage

## Pressure, temperature and humidity
The following graphs show relative humidity (%), pressure (mbar) and temperature (deg C). We can observe daily temperature spikes that are clearly above the environmental temperature and thus also the humidity readings are not very representative of the environment.

enc_humid

enc_press

enc_temp

env_humid

env_press

env_temp

## Radiation
Radiation measurements are observed for any significant out of range values, we observe only the background radiation with a rather random pattern between units, ranging between 25 and 33 cpm for the compensated tube and 23 to 36 cpm for uncompensated.

lnd_7318c

lnd_7318u

## OPC Air sensor PM values
Alpnasense OPC-N2 sensors return values of PM1, PM2.5 and PM10 counts in ug/m3 concentration. 

opc_pm01_0

opc_pm02_5

opc_pm10_0

## PMS Air sensor PM values
APMS sensors returns values of PM1, PM2.5 and PM10 counts in ug/m3 concentration. We observe that PMS sensors measure concentration in more discrete levels and genrally agree with OPC measurements.

pms_pm01_0

pms_pm02_5

pms_pm10_0

## OPC Air sensor raw bin count values
These raw bin count values are graphed for convenience of analysis.

opc_c00_38

opc_c00_54

opc_c01_00

opc_c02_10

opc_c05_00

opc_c10_00

## PMS Air sensor raw bin count values
These raw bin count values are graphed for convenience of analysis.

pms_c00_30

pms_c00_50

pms_c01_00

pms_c02_50

pms_c05_00

pms_c10_00

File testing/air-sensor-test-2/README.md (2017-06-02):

## Air Sensor test - 7 unit analysis
To validate the performance of air sensors a test has been performed in the clean air chamber with all these units present simoultaneously for a duration of about 4 hours, each unit reported measurements over that time and the graphs below show the results. For the first part of the test the chamber was active and air was filtered, for the second part it was turned off and ambien air filled the chamber.

units in chamber

Devices as a part of this experiment:
- 114699387
- 230442684
- 1094924990
- 2670856639
- 3373827677
- 3714913954
- 4267748403

Tasks as the outcome of this experiment:

3714913954: check battery reporting and charging

230442684: replace ENV - BME0 sensor

## Battery status
The following graphs show battery charge percentage (%), current (mA) and voltage results (V). We can observe that all units are discharging at a similar rate during the experimentation, except unit 3714913954 which is for some reason reporting contant voltage.

bat_charge

bat_current

bat_voltage

## Pressure, temperature and humidity
The following graphs show relative humidity (%), pressure (mbar) and temperature (deg C). We can observe the variance of co-located units in the measured values. Temperature between all units is within 1degC, while humidiry varies for about 2-3%, which is as specified for the [BME280](https://www.bosch-sensortec.com/bst/products/all_products/bme280) sensor in teh datasheet. Note vairation is between units as such, not just an error to the actual valuen of all sensors. ENV_HUMID value of unit 230442684 stands out and likely requires a sensor replacement.

enc_humid

enc_press

enc_temp

env_humid

env_press

env_temp

## Radiation
Radiation measurements are observed for any significant out of range values, we observe only the background radiation with a rather random pattern between units, ranging between 25 and 33 cpm for the compensated tube and 23 to 36 cpm for uncompensated.

lnd_7318c

lnd_7318u

## OPC Air sensor PM values
Alpnasense OPC-N2 sensors return values of PM1, PM2.5 and PM10 counts in ug/m3 concentration. We observe that all sensors converge to 0 for the first part of the test in the clean air chamber and rise to the ambient level when the filtering is turned off. Ambient values have a reasonably large deviation between sensors as such, in the given case up to 20 ug/m3 variation at any given time. Note that sensors have consistenlty higher or lower values across all particle sizes and thus deviation is unit specific.

opc_pm01_0

opc_pm02_5

opc_pm10_0

## PMS Air sensor PM values
APMS sensors returns values of PM1, PM2.5 and PM10 counts in ug/m3 concentration. We observe that all sensors converge to 0 for the first part of the test in the clean air chamber and rise to the ambient level when the filtering is turned off. Ambient values have a reasonably large deviation between sensors as such, in the given case up to 10 ug/m3 variation at any given time. Note that sensors have consistenlty higher or lower values across all particle sizes and thus deviation is unit specific.

pms_pm01_0

pms_pm02_5

pms_pm10_0

## OPC Air sensor raw bin count values
These raw bin count values are graphed for convenience of analysis.

opc_c00_38

opc_c00_54

opc_c01_00

opc_c02_10

opc_c05_00

opc_c10_00

## PMS Air sensor raw bin count values
These raw bin count values are graphed for convenience of analysis.

pms_c00_30

pms_c00_50

pms_c01_00

pms_c02_50

pms_c05_00

pms_c10_00

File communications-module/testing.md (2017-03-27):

### Communications Module testing:
Purpose of this testing is to verify correct operation of assembled circuit boards.

## Voltage and current check:
Validating correct operation of power switches, supplies and other devices.

* Connect Amp meter on J15 on IoT Battery Pack
  * Expect reading of about 0.12mA
* Connect IoT battery pack with IDC10 cable to Comms board
  * Expect D3 to start blinking and about 28mA current draw
* Connect computer to programmer with micro-USB cable
  * Expect the device to appear as MBED USB drive.
  * Upload solarcast-powerdebug-on.bin firmware
* Disconnect USB and power cycle
  * Expect D1 red LED to be on
  * Expect D2 yellow LED to be on
  * Expect D3 red LED to be blinking
  * Expect current draw of about 27mA
 * Expect the following voltages on power switch outputs
   * JP17 - TWI - 3.3V
   * JP22 - FONA_VBAT - Vbat (3.5-4.2V)
   * JP18 - FONA_3V3 - 3.3V
   * JP19 - GPS - 3.3V
   * JP21 - LORA - 5.0V
   * JP20 - ROCK - 5.0V
   * JP11 - AIR - 5.0V
   * JP12 - GEIGER - 5.0V
 * Expect PWR-SWITCH-OC pin to be high (3.3V)

### Chip level debugging

* U1 nRF52832:
  * measure 3.3V on pins 18
  * check if programming OK

* U4 PWR_CONN:
  * measure 5V on pin 3
  * measure 3.3V on pin 5
  * measure battery voltage on pin 7
  * check ENABLE-5V
  * check ENABLE-VBAT
  * I2C scan
  
* U3 TPS2064:
  * measure 5V on pin 2
  * measure 3.3V on pins 5,8
  * check ENABLE-RESERV, measure 5V on pin 6
  * check ENABLE-BACKUP, measure 5V on pin 7

* U5 TPS2064:
  * measure 5V on pin 2
  * measure 3.3V on pins 5,8
  * check ENABLE-RESERV, measure 5V on pin 6
  * check ENABLE-BACKUP, measure 5V on pin 7
  
* J1 IDC12:
  * measure 5V on pin 1
  * I2C scan
  * check SPI
  * check UART
 
* P2 USB_A:
  * check if programming OK
  * check pulses on GEIGER0,GEIGER1

* P3,P4 USB_A:
  * check if programming OK
  * I2C scan
  
* U7,U9 I2C_connector:
  * check 3.3V on pin 2
  * I2C scan
  
* U8 BME280:
  * check 3.3V on pins 2,6,8
  * I2C scan
  
* U10 LIS3DH_breakout:
  * check 3.3V on pin 1
  * I2C scan
  * check ACC_INT
  
* U6 TPS2064:
  * measure 3.3V on pins 2,5,8
  * check ENABLE-TWI, measure 3.3V on pin 7

* U11 FONA_3G:
  * check VBAT on pin 2
  * check 3.3V on pin 4
  * check UART

* U13 RockBLOCK:
  * check 5V on pins 4,8
  * check UART
  * check 3.3V on pin 12

* U16 FGPMMOPA6H GPS:
  * check 3.3V on pin 1
  * check VBAT on pin 4
  * check LED D3 blinking
  * check UART
  
* U19 Gateway Module LORA:
  * check 5V on pins 2,4
  * check UART

* U14,U18 SN74LV4052A:
  * check UART multiplexing

* U20 TPS2064:
  * measure VBAT on pin 2
  * measure 3.3V on pins 5,8
  * check ENABLE-FONA, measure VBAT on pin 7
  
* U12 TPS2064:
  * measure 3.3V on pin 2
  * measure 3.3V on pins 5,8
  * check ENABLE-FONA, measure 3.3V on pin 7
  * check ENABLE-GPS, measure 3.3V on pin 6
  
* U15 TPS2064:
  * measure 5V on pin 2
  * measure 3.3V on pins 5,8
  * check ENABLE-ROCK, measure 5V on pin 7
  * check ENABLE-LORA, measure 5V on pin 6

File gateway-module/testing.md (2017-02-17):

#Gateway Module testing:

* U4 TPS79133:
	* measure 3.3V on pin 5

* U5 BME280:
	* measure 3.3V on pins 2,5,6,8
	* I2C scan
	
* U1 small_i2c_oled:
	* measure 3.3V on pin 1
	* I2C scan
	
* U2 RaspberryPi:
	* measure 5V on pins 2,4

* U3 RN2483:
	* measure 3.3V on pins 12,32,34
	* check UART communication

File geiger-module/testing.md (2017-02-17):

#Geiger Module testing:

* U2 TPS79133:
	* measure 3.3V on pin 5
	
* U5 BME280:
	* measure 3.3V on pins 2,5,6,8
	* I2C scan

* U1 iRover1:
	* check LED D4 blinking
	
* U4 iRover2:
	* check LED D5 blinking
	
* U3 nRF52832:
	* measure 3.3V on pins 18
	* check if programming OK

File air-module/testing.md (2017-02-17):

#Air Module testing:

* U2 nRF52832:
	* measure 3.3V on pins 8,9,18
	* check if programming OK
	
* U4 TPS2064:
	* measure 5V on pin 2
	* set EN_PLANT='0', measure 0V on pin 7
	* set EN_PLANT='1', measure 5V on pin 7
	* set EN_ALPHA='0', measure 0V on pin 6
	* set EN_ALPHA='1', measure 5V on pin 6
	* measure 3.3V on pins 5,8
	
* U5 BME280:
	* measure 3.3V on pins 2,5,6,8
	* I2C scan
	
* U6 TPS79133:
	* measure 3.3V on pin 5
	
* P1 USB_OTG:
	* check if programming OK
	* measure 5V on pin 1
	
* J2 ARM_SWD_SMALL:
	* check if programming OK
	
* J1 IDC12:
	* measure 5V on pin 1
	* I2C scan
	* check SPI
	* check UART
	
* U1 Alphasense_OPC-N2:
	* measure 5V on pin 1
	* check SPI communication
	
* U3 Plantower_PM2.5_PMS_5003:
	* measure 5V on pin 1
	* check UART communication
	* I2C scan

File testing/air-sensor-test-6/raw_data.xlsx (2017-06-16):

service_uploaded | device | lnd_7318u | lnd_7318c | bat_voltage | bat_charge | bat_current | env_temp | env_humid | env_press | enc_temp | enc_humid | enc_press | pms_pm01_0 | pms_pm02_5 | pms_pm10_0 | pms_c00_30 | pms_c00_50 | pms_c01_00 | pms_c02_50 | pms_c05_00 | pms_c10_00 | opc_pm01_0 | opc_pm02_5 | opc_pm10_0 | opc_c00_38 | opc_c00_54 | opc_c01_00 | opc_c02_10 | opc_c05_00 | opc_c10_00
2017-06-15 17:27 | 114699387 | 39 | 37 | 3.851094 | 52.971874 | -335.453125 |  |  |  |  |  |  | 8 | 9 | 9 | 92169 | 25643 | 2318 | 21 | 10 | 0 | 1.881251 | 2.535278 | 4.136048 | 1436 | 410 | 132 | 45 | 4 | 0
2017-06-15 17:27 | 114699387 | 41 | 33
2017-06-15 17:27 | 114699387 | 35 | 35
2017-06-15 17:27 | 114699387 | 38 | 40 | 3.848485 | 54.526173 | -215.09375 |  |  |  |  |  |  | 8 | 9 | 10 | 91527 | 25559 | 2503 | 57 | 10 | 0 | 1.876341 | 2.500195 | 4.481369 | 1412 | 431 | 142 | 33 | 5 | 1
2017-06-15 17:27 | 114699387 | 39 | 37
2017-06-15 18:42 | 114699387 | 38 | 35
2017-06-15 18:42 | 114699387 | 42 | 34 | 3.832828 | 54.894531 | 2.28125 |  |  |  |  |  |  | 8 | 11 | 11 | 96372 | 26529 | 2940 | 128 | 22 | 0 | 2.699908 | 3.530345 | 4.712555 | 2249 | 571 | 217 | 46 | 5 | 0
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

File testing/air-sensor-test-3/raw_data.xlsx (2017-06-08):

service_uploaded | device | lnd_7318u | lnd_7318c | bat_voltage | bat_charge | bat_current | env_temp | env_humid | env_press | enc_temp | enc_humid | enc_press | pms_pm01_0 | pms_pm02_5 | pms_pm10_0 | pms_c00_30 | pms_c00_50 | pms_c01_00 | pms_c02_50 | pms_c05_00 | pms_c10_00 | opc_pm01_0 | opc_pm02_5 | opc_pm10_0 | opc_c00_38 | opc_c00_54 | opc_c01_00 | opc_c02_10 | opc_c05_00 | opc_c10_00
2017-06-07 13:23 | 114699387
2017-06-07 13:23 | 114699387
2017-06-07 13:23 | 114699387 |  |  |  |  |  | 28.163681 | 14.601347 | 986.952637 | 23.834 | 29.651361 | 985.819824 | 2 | 3 | 3 | 44898 | 12212 | 1280 | 36 | 13 | 0 | 2.581231 | 3.705191 | 7.577393 | 1546 | 695 | 250 | 57 | 8 | 1
2017-06-07 13:43 | 114699387 |  |  |  |  |  | 27.23217 | 17.738173 | 986.992493 | 22.053766 | 36.835056 | 985.969727 | 5 | 7 | 7 | 69735 | 19706 | 2362 | 139 | 28 | 0 | 3.521798 | 4.960756 | 12.174576 | 2314 | 914 | 301 | 101 | 14 | 3
2017-06-07 13:48 | 114699387 | 29 | 28 |  |  |  | 26.979044 | 18.696436 | 987.119507 | 21.716833 | 38.568218 | 985.982971 | 2 | 2 | 3 | 39351 | 10567 | 1167 | 13 | 0 | 0 | 2.600255 | 3.692909 | 8.447979 | 1546 | 604 | 216 | 58 | 10 | 1
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

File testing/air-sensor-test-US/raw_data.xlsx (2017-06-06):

service_uploaded | device | lnd_7318u | lnd_7318c | bat_voltage | bat_charge | bat_current | env_temp | env_humid | env_press | enc_temp | enc_humid | enc_press | pms_pm01_0 | pms_pm02_5 | pms_pm10_0 | pms_c00_30 | pms_c00_50 | pms_c01_00 | pms_c02_50 | pms_c05_00 | pms_c10_00 | opc_pm01_0 | opc_pm02_5 | opc_pm10_0 | opc_c00_38 | opc_c00_54 | opc_c01_00 | opc_c02_10 | opc_c05_00 | opc_c10_00
2017-05-17 07:39 | 1238569003 | 22 | 23 | 3.912125 | 85.582031 | 1.4375 | 17.92981 | 49.742458 | 1011.588806 |  |  |  | 2 | 3 | 3 | 37722 | 8332 | 651 | 66 | 22 | 19 | 0.766231 | 1.136636 | 4.348765 | 561 | 196 | 100 | 29 | 2 | 4
2017-05-17 07:39 | 1238569003 | 23 | 26 |  |  |  | 18.101309 | 48.524059 | 1011.635559 |  |  |  | 3 | 4 | 5 | 47607 | 11432 | 944 | 126 | 40 | 20 | 1.091829 | 1.514614 | 5.196612 | 859 | 244 | 86 | 37 | 8 | 3
2017-05-17 07:39 | 1238569003 | 22 | 23 |  |  |  | 18.393866 | 48.355225 | 1011.617554 |  |  |  | 6 | 7 | 8 | 112371 | 21817 | 1060 | 219 | 30 | 20 | 0.822346 | 1.183021 | 3.128916 | 610 | 218 | 76 | 33 | 4 | 1
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

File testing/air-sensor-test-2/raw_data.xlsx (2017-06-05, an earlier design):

service_uploaded | device | lnd_7318u | lnd_7318c | bat_voltage | bat_charge | bat_current | env_temp | env_humid | env_press | enc_temp | enc_humid | enc_press | pms_pm01_0 | pms_pm02_5 | pms_pm10_0 | pms_c00_30 | pms_c00_50 | pms_c01_00 | pms_c02_50 | pms_c05_00 | pms_c10_00 | opc_pm01_0 | opc_pm02_5 | opc_pm10_0 | opc_c00_38 | opc_c00_54 | opc_c01_00 | opc_c02_10 | opc_c05_00 | opc_c10_00
2017-06-05 09:09 | 129232559 |  |  |  |  |  | 26.307604 | 38.42868 | 983.934326 |  |  |  | 0 | 0 | 0 | 15087 | 4461 | 505 | 11 | 0 | 0 | 0.466492 | 0.611397 | 0.877348 | 430 | 156 | 34 | 10 | 1 | 0
2017-06-05 09:14 | 129232559 | 29 | 27 | 4.159234 | 96.933594 | 2.296875 | 26.825708 | 36.53265 | 983.828796 |  |  |  | 0 | 0 | 0 | 807 | 260 | 12 | 0 | 0 | 0 | 0.027613 | 0.035038 | 0.035761 | 23 | 8 | 2 | 0 | 0 | 0
2017-06-05 09:19 | 129232559
2017-06-05 09:19 | 129232559
2017-06-05 09:19 | 129232559
2017-06-05 09:19 | 129232559
2017-06-05 09:19 | 129232559
2017-06-05 09:20 | 129232559
2017-06-05 09:20 | 129232559
2017-06-05 09:20 | 129232559
2017-06-05 09:20 | 129232559
2017-06-05 09:21 | 129232559
2017-06-05 09:21 | 129232559
2017-06-05 09:21 | 129232559
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

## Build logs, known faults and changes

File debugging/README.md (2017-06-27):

# Debugging problems on Solarcast units
During build time some errors have been encountered int he constructions/assembly process, hereby we document them such that they can be recognized and solved. One can best approach this using command `check` in the Slack interface system.

## ENV sensor failure - BME0

```
Measurement Counts:
  Bat     45  (3.88-3.98V, -763.3 to 9.4mA, 74-87%)
  Env      0
  Enc      6  (14.6-30.7C, 22.2-72.4%, 982-985Pa)
  Pms     91  (0-12pm1, 0-20pm2.5, 0-21pm10)
  Opc     91  [1 OOR 2017-06-26T05:28:55Z]  (1.1211-127.0359pm1, 1.9325-232.8186pm2.5, 3.7093-1118.9633pm10)
  LndU   113  (30-89cpm)
  LndC   113  (29-52cpm)
```

 Known solutions:
  * Resolder sensor
  * Swap sensor
  
## ENC sensor failure - BME1
The check output looks something like this, no measurement for Enc received.

```
Measurement Counts:
  Bat     45  (3.89-3.94V, -381.3 to 10.0mA, 63-68%)
  Env     65  (13.0-38.1C, 1.3-103.0%, 980-984Pa)
  Enc      0
  Pms     65  (0-12pm1, 0-20pm2.5, 0-22pm10)
  Opc     65  (0.7475-134.6814pm1, 0.9859-219.7148pm2.5, 3.4837-474.3000pm10)
  LndU   101  (33-90cpm)
  LndC   101  (29-53cpm)
```
  
 Known solutions:
  * Resolder sensor
  * Swap sensor
  
## Fona failure
FONA 3G module can fail in a number of ways, though the check mechanism we can see this as follows:

* upload gaps greater then 1-2h
* Device errors:
  * Fona power
  * Fona antenna

```
Inter-upload Gaps: (<1m to 11h 10m)
  6-12hr    9% (1)
  1-2hr    82% (9)
    1-4m    9% (1)

Connection errors:
  None

Measurement Counts:
  Bat     29  (3.89-3.91V, -51.3 to 10.8mA, 21-31%)
  Env     50  [1 OOR 2017-06-25T09:45:55Z]  (13.3-38.6C, -0.7-100.4%, 981-985Pa)
  Enc      5  (13.7-36.0C, 12.7-89.4%, 981-985Pa)
  Pms     50  (2-13pm1, 2-21pm2.5, 2-24pm10)
  Opc     50  [1 OOR 2017-06-26T05:35:53Z]  (1.8324-133.7118pm1, 2.4482-258.5451pm2.5, 4.1061-1731.0664pm10)
  LndU    64  (32-90cpm)
  LndC    64  (29-51cpm)

Device errors:
  Fona Power   2
  Fona Antenna 291
  ```
  
Known solutions:
 * Replace antenna, either bad uFL connector or damaged connetion of coax at the antenna
 * Crimp uFL connector just a bit to give it a better contact

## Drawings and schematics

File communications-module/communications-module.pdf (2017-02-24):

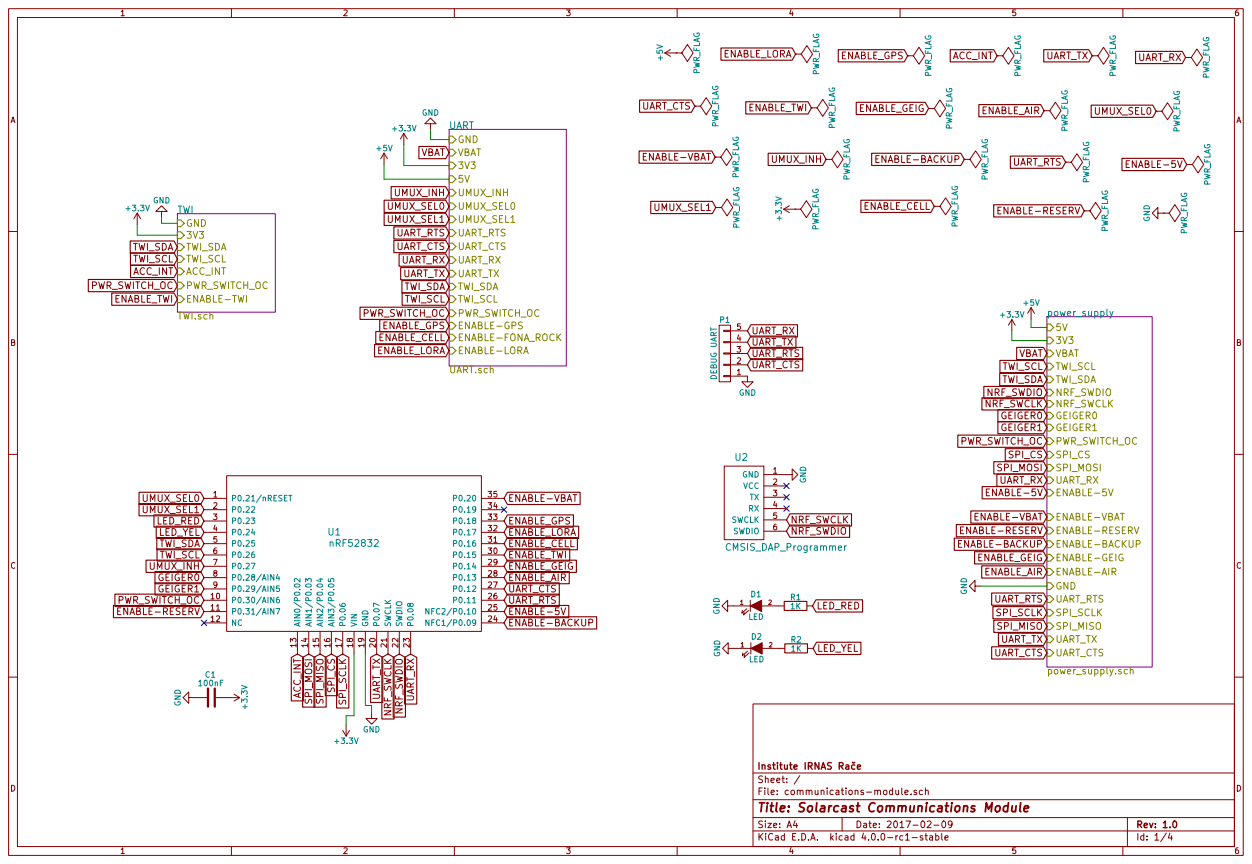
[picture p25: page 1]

+3.3V TWI TWI.sch GND

File: communications-module.sch Sheet: /
Id: 1/4 Title: Solarcast Communications Module

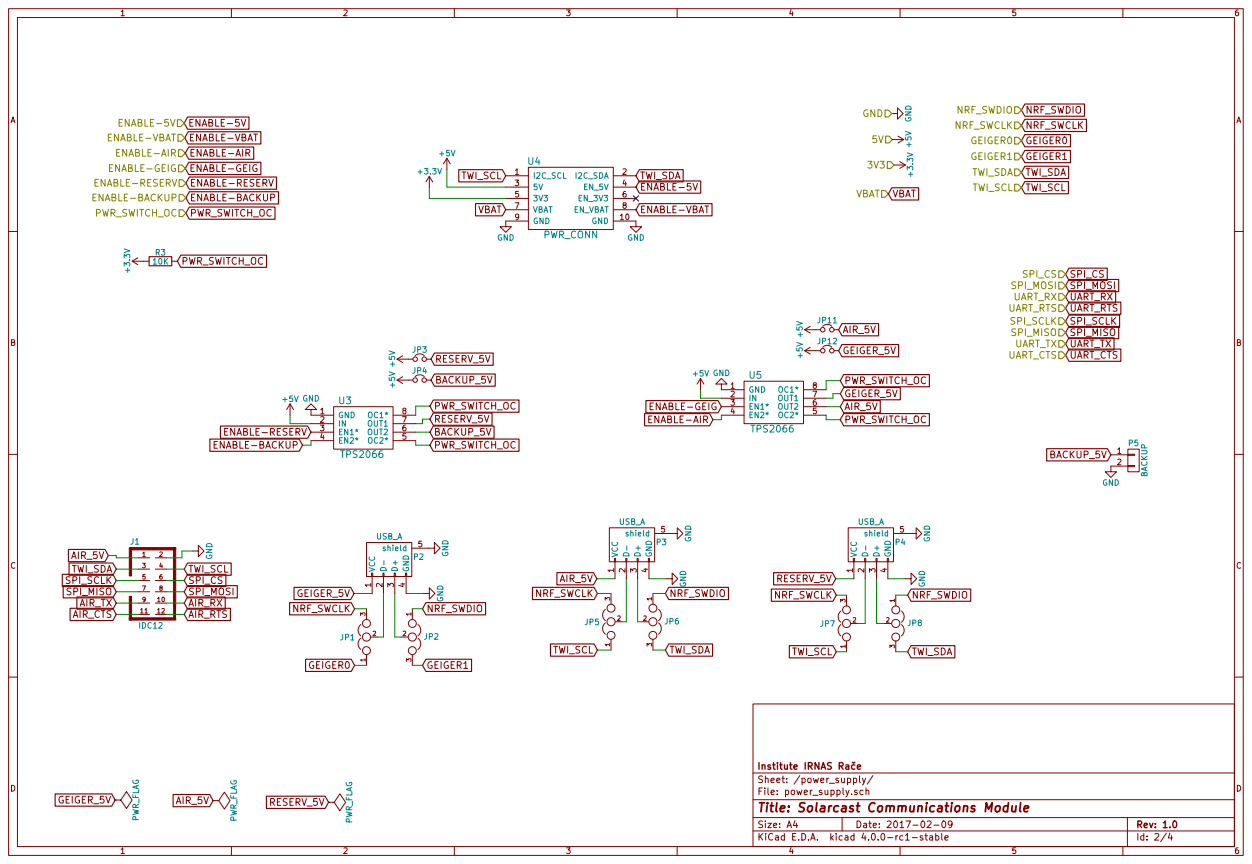
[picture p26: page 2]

Institute IRNAS Rae
Sheet: /power_supply/
File: power_supply.sch
Id: 2/4 Title: Solarcast Communications Module

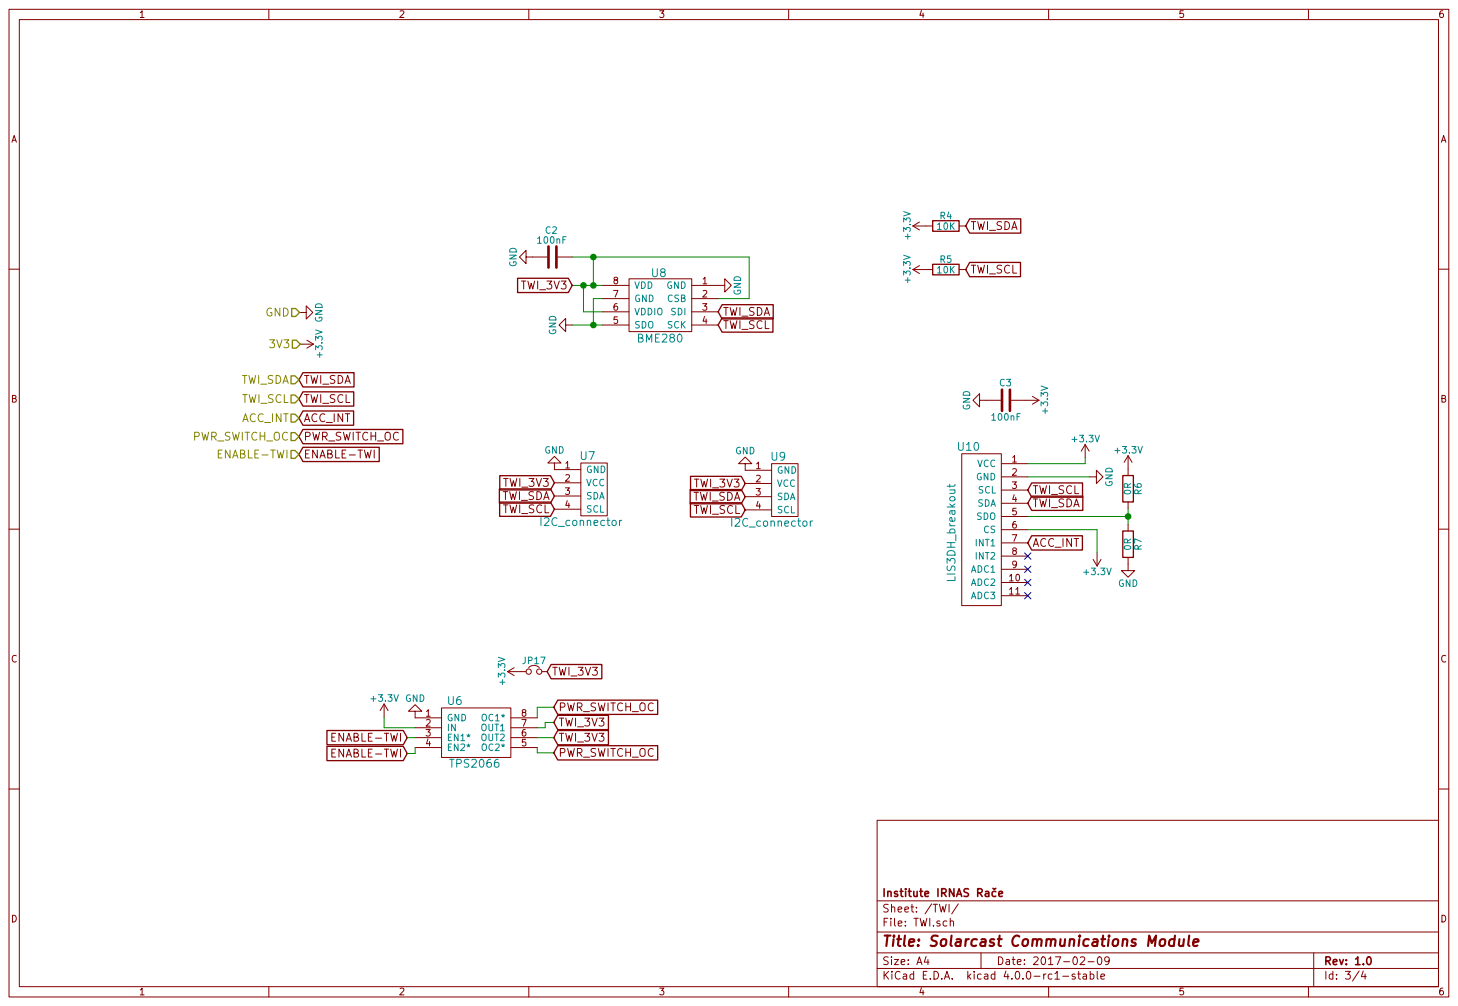
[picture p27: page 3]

Institute IRNAS Rae
File: TWI.sch Sheet: /TWI/
Id: 3/4 Title: Solarcast Communications Module

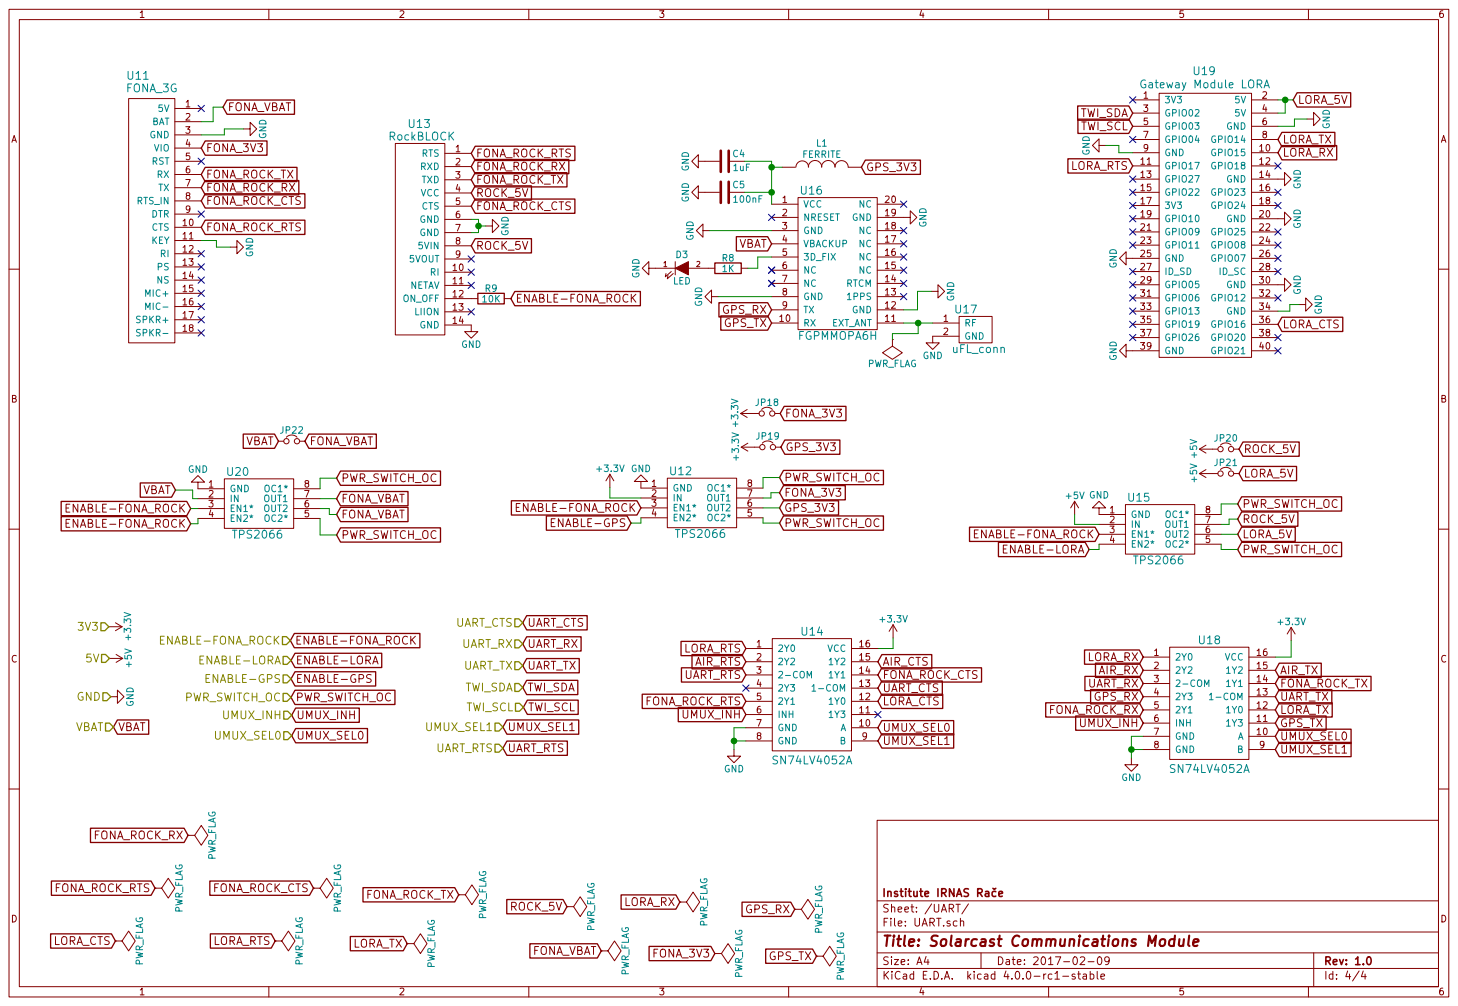
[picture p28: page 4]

Institute IRNAS Rae
File: UART.sch Sheet: /UART/
Id: 4/4 Title: Solarcast Communications Module

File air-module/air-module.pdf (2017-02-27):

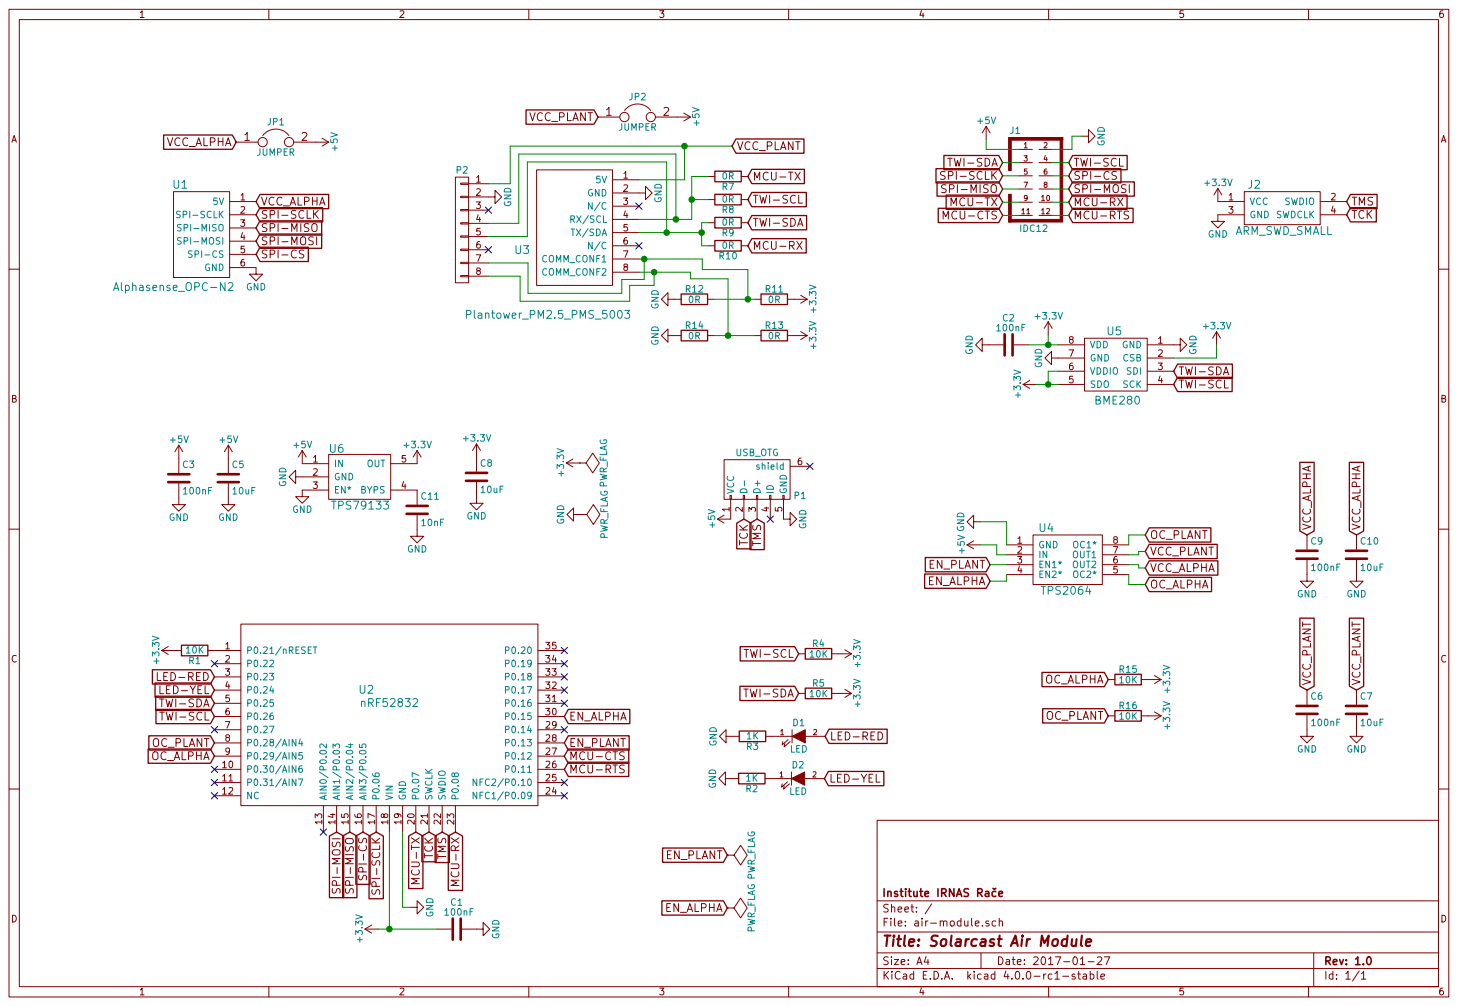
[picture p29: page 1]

File: air-module.sch Sheet: /
Id: 1/1 Title: Solarcast Air Module

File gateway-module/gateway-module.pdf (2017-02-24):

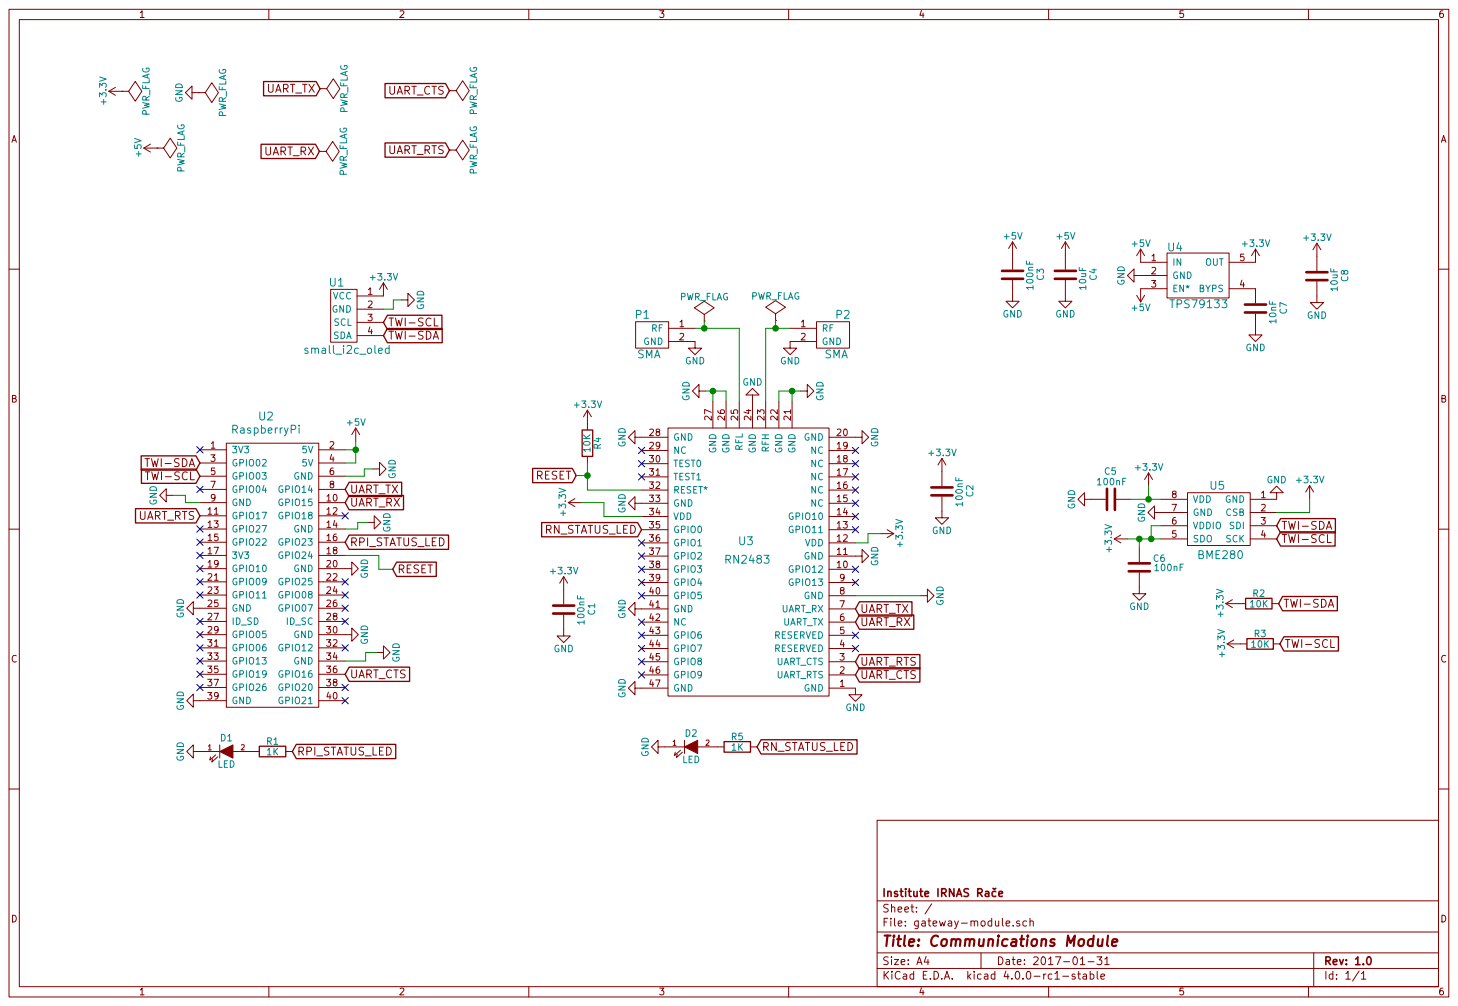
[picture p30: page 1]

File: gateway-module.sch Sheet: /
Id: 1/1 Title: Communications Module

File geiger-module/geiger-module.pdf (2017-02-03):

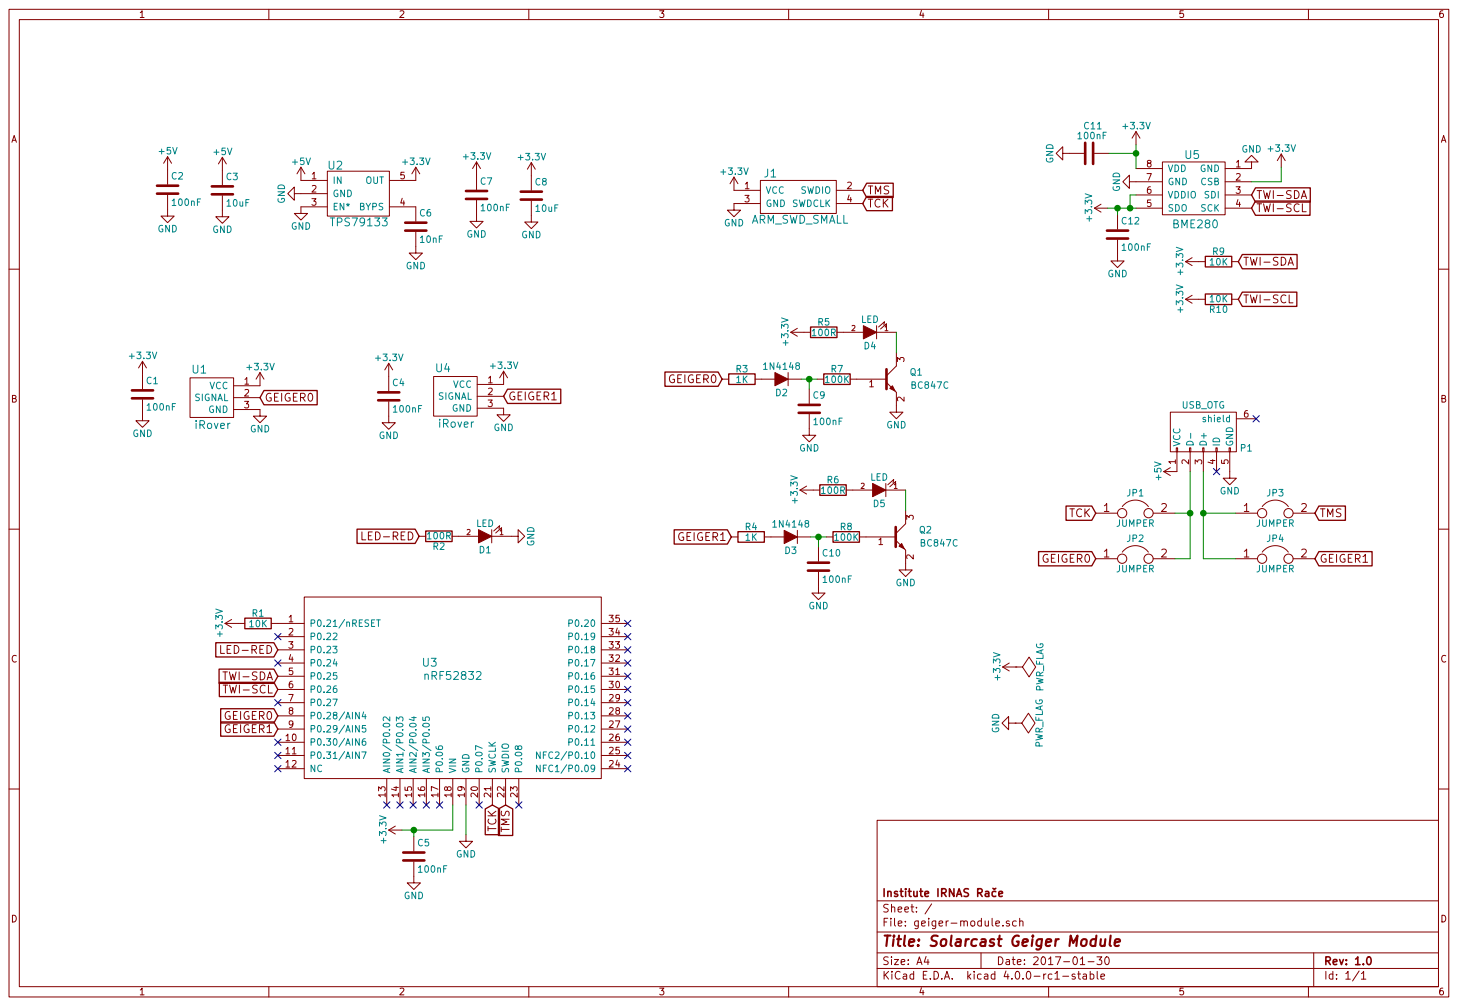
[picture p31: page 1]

File: geiger-module.sch Sheet: /
Id: 1/1 Title: Solarcast Geiger Module

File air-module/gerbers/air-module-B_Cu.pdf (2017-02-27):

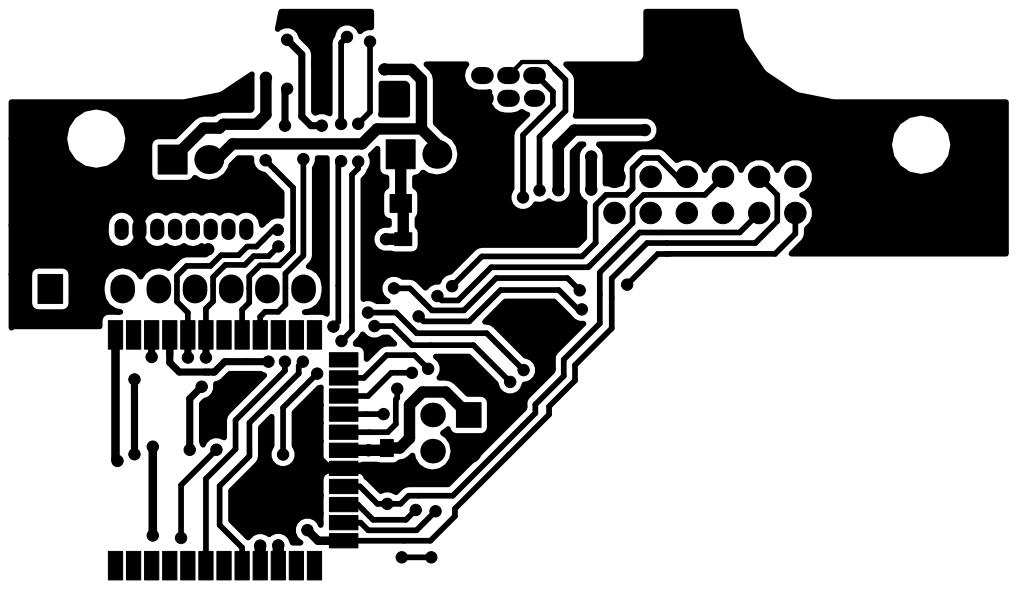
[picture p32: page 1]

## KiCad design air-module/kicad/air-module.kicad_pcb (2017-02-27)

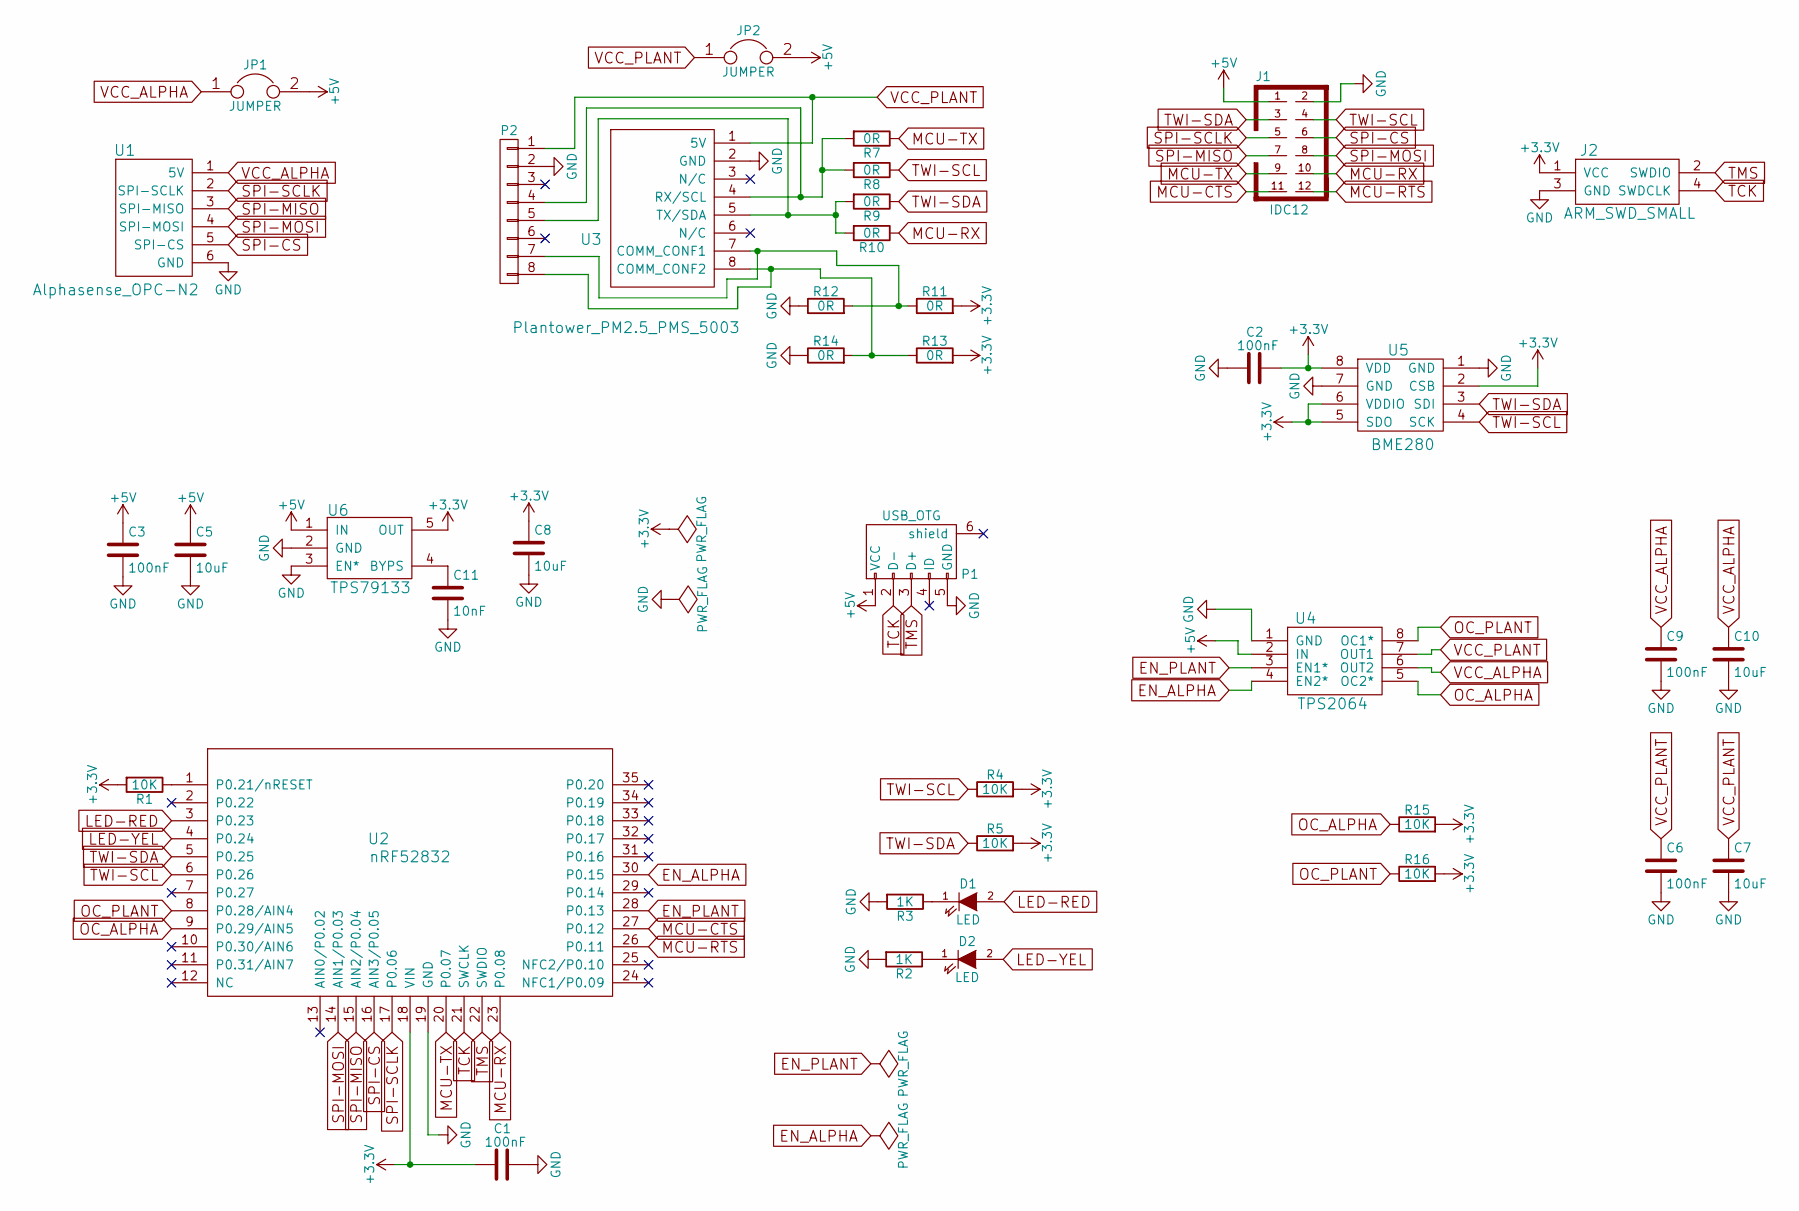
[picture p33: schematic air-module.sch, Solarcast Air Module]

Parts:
C1, C2, C3, C6, C9: 100nF; 0603_HandSoldering
C5, C7, C8, C10: 10uF; 0805_HandSoldering
C11: 10nF; 0603_HandSoldering
D1, D2: LED; LED_0603_HandSoldering
J1: IDC12; IDC12_connector
J2: ARM_SWD_SMALL; Socket_Strip_Straight_2x02
JP1, JP2: JUMPER; Socket_Strip_Straight_1x02
P1: USB_OTG; DCP-USBCB-SC
P2: CONN_01X08; Molex-53047-0810
R1, R4, R5, R15, R16: 10K; 0603_HandSoldering
R2, R3: 1K; 0603_HandSoldering
R7, R8, R9, R10, R11, R12, R13, R14: 0R; 0603_HandSoldering
U1: Alphasense_OPC-N2; Molex_501331-0607
U2: nRF52832; nRF52832-SMD
U3: Plantower_PM2.5_PMS_5003; Socket_Strip_Straight_1x08
U4: TPS2064
U5: BME280
U6: TPS79133

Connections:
+3V3: C1.2, C2.1, C8.1, J2.1 (VCC), R1.2, R4.2, R5.2, R11.2, R13.2, R15.2, R16.2, U2.18 (VIN), U5.2 (CSB), U5.5 (SDO), U5.6 (VDDIO), U5.8 (VDD), U6.5 (OUT)
+5V: C3.1, C5.1, J1.1, JP1.2, JP2.2, P1.1 (VCC), U4.2 (IN), U6.1 (IN)
EN_ALPHA: U2.30 (P0.15), U4.4 (EN2*)
EN_PLANT: U2.28 (P0.13), U4.3 (EN1*)
GND: C1.1, C2.2, C3.2, C5.2, C6.2, C7.2, C8.2, C9.2, C10.2, C11.2, J1.2, J2.3 (GND), P1.5 (GND), P2.2, R2.2, R3.2, R12.1, R14.1, U1.6 (GND), U2.19 (GND), U3.2 (GND), U4.1 (GND), U5.1 (GND), U5.7 (GND), U6.2 (GND), U6.3 (EN*)
LED-RED: D1.2 (A), U2.3 (P0.23)
LED-YEL: D2.2 (A), U2.4 (P0.24)
MCU-CTS: J1.11, U2.27 (P0.12)
MCU-RTS: J1.12, U2.26 (P0.11)
MCU-RX: J1.10, R10.1, U2.23 (P0.08)
MCU-TX: J1.9, R7.1, U2.20 (P0.07)
unnamed: C11.1, U6.4 (BYPS)
unnamed: D1.1 (K), R3.1
unnamed: D2.1 (K), R2.1
unnamed: P2.4, R7.2, R8.2, U3.4 (RX/SCL)
unnamed: P2.5, R9.2, R10.2, U3.5 (TX/SDA)
unnamed: P2.7, R11.1, R12.2, U3.7 (COMM_CONF1)
unnamed: P2.8, R13.1, R14.2, U3.8 (COMM_CONF2)
unnamed: R1.1, U2.1 (P0.21/nRESET)
OC_ALPHA: R15.1, U2.9 (P0.29/AIN5), U4.5 (OC2*)
OC_PLANT: R16.1, U2.8 (P0.28/AIN4), U4.8 (OC1*)
SPI-CS: J1.6, U1.5 (SPI-CS), U2.16 (AIN3/P0.05)
SPI-MISO: J1.7, U1.3 (SPI-MISO), U2.15 (AIN2/P0.04)
SPI-MOSI: J1.8, U1.4 (SPI-MOSI), U2.14 (AIN1/P0.03)
SPI-SCLK: J1.5, U1.2 (SPI-SCLK), U2.17 (P0.06)
TCK: J2.4 (SWDCLK), P1.2 (D-), U2.21 (SWCLK)
TMS: J2.2 (SWDIO), P1.3 (D+), U2.22 (SWDIO)
TWI-SCL: J1.4, R4.1, R8.1, U2.6 (P0.26), U5.4 (SCK)
TWI-SDA: J1.3, R5.1, R9.1, U2.5 (P0.25), U5.3 (SDI)
VCC_ALPHA: C9.1, C10.1, JP1.1, U1.1 (5V), U4.6 (OUT2)
VCC_PLANT: C6.1, C7.1, JP2.1, P2.1, U3.1 (5V), U4.7 (OUT1)

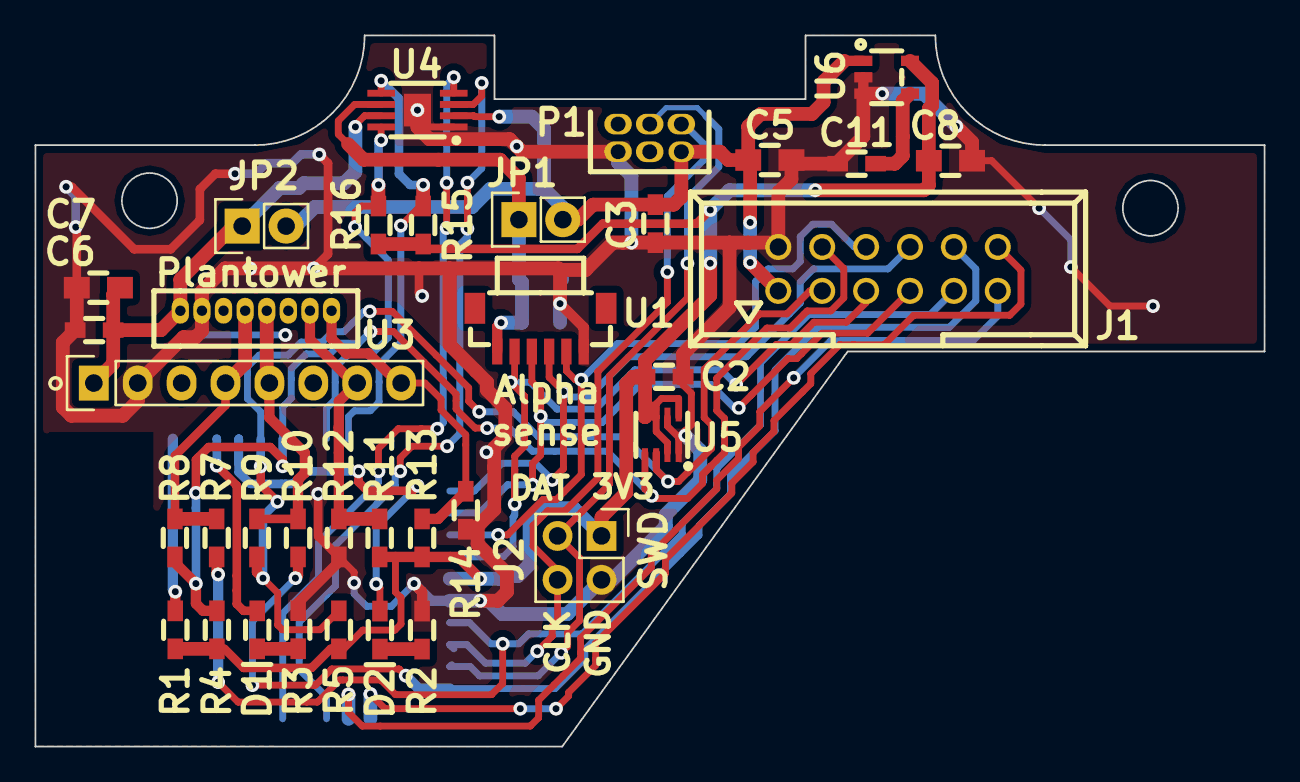
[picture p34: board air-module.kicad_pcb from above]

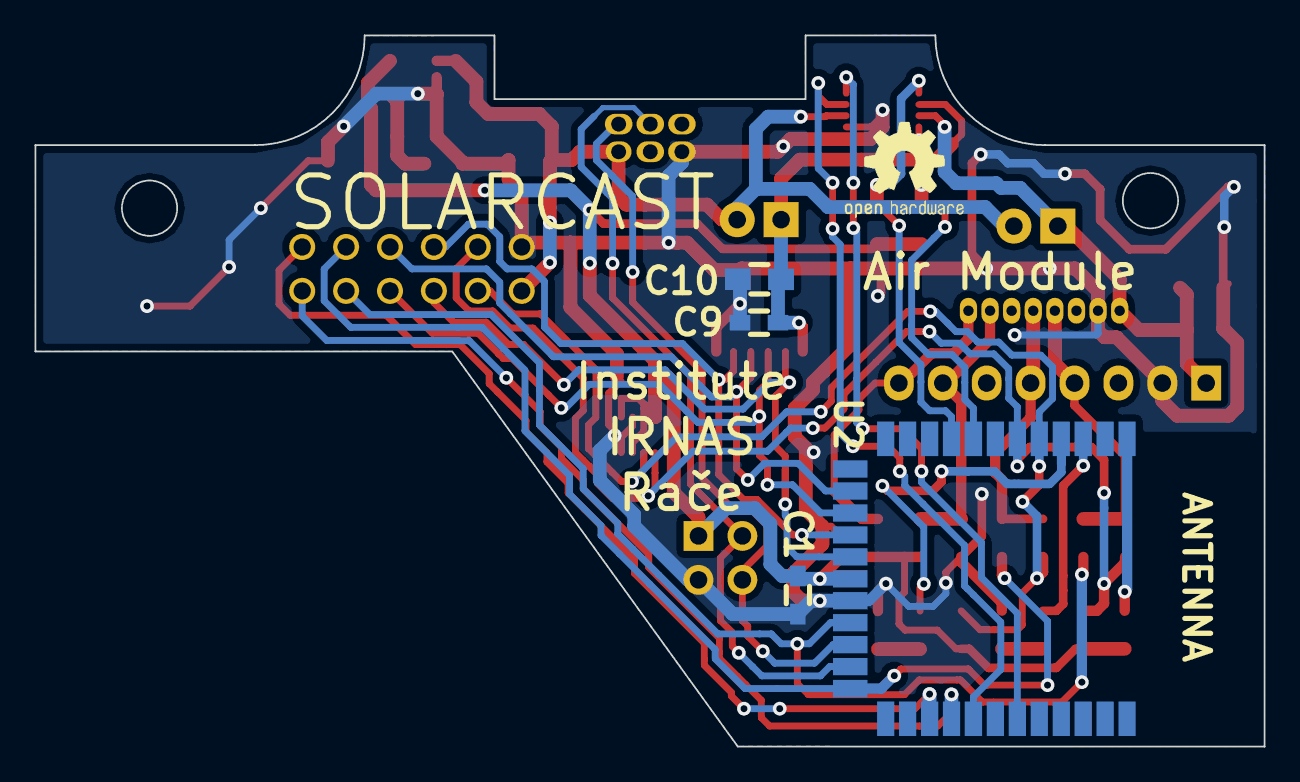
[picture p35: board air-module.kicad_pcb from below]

Board: 2 copper layers, 71.1 x 41.1 mm, 39 parts (4 on the bottom side), 31 nets.

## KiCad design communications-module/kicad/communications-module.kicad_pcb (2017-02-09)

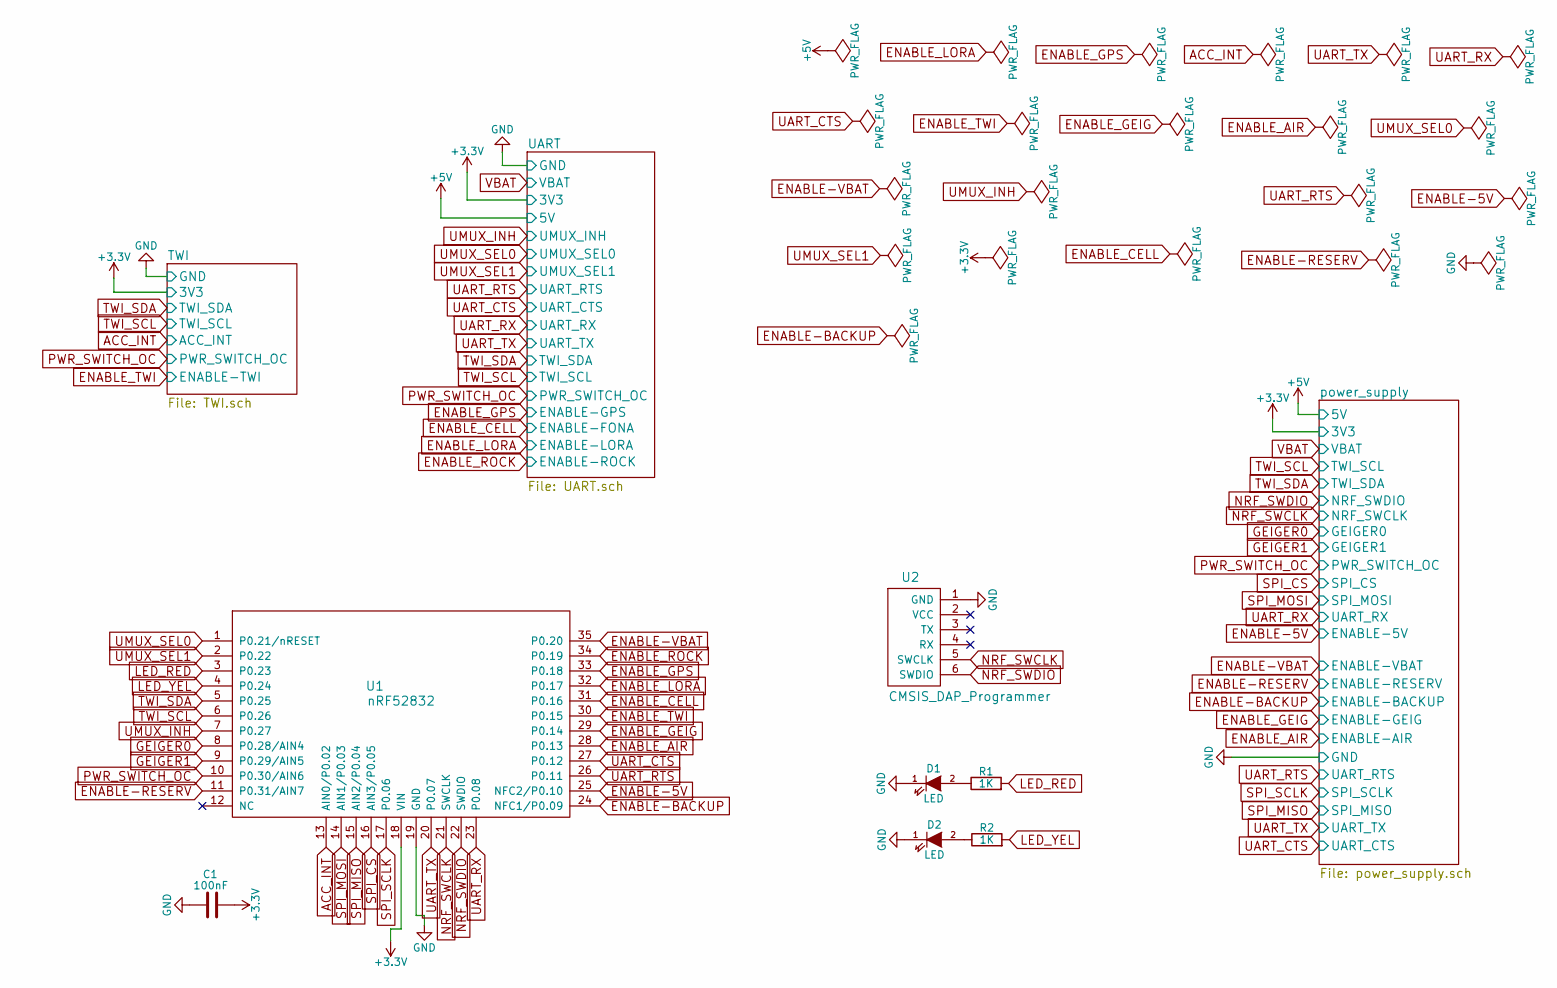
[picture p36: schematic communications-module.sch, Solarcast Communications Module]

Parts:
C1: 100nF; 0603_HandSoldering
D1, D2: LED; LED_0603_HandSoldering
R1, R2: 1K; 0603_HandSoldering
U1: nRF52832; nRF52832-SMD
U2: CMSIS_DAP_Programmer; CMSIS_DAP_Breakout

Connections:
+3V3: C1.2, U1.18 (VIN); also elsewhere on the board
ACC_INT: U1.13 (AIN0/P0.02); also elsewhere on the board
ENABLE-5V: U1.25 (NFC2/P0.10); also elsewhere on the board
ENABLE-AIR: U1.28 (P0.13); also elsewhere on the board
ENABLE-BACKUP: U1.24 (NFC1/P0.09); also elsewhere on the board
ENABLE-FONA: U1.31 (P0.16); also elsewhere on the board
ENABLE-GEIG: U1.29 (P0.14); also elsewhere on the board
ENABLE-GPS: U1.33 (P0.18); also elsewhere on the board
ENABLE-LORA: U1.32 (P0.17); also elsewhere on the board
ENABLE-RESERV: U1.11 (P0.31/AIN7); also elsewhere on the board
ENABLE-ROCK: U1.34 (P0.19); also elsewhere on the board
ENABLE-TWI: U1.30 (P0.15); also elsewhere on the board
ENABLE-VBAT: U1.35 (P0.20); also elsewhere on the board
GEIGER0: U1.8 (P0.28/AIN4); also elsewhere on the board
GEIGER1: U1.9 (P0.29/AIN5); also elsewhere on the board
LED_RED: R1.2, U1.3 (P0.23)
LED_YEL: R2.2, U1.4 (P0.24)
NRF_SWCLK: U1.21 (SWCLK), U2.5 (SWCLK); also elsewhere on the board
NRF_SWDIO: U1.22 (SWDIO), U2.6 (SWDIO); also elsewhere on the board
unnamed: D1.2 (A), R1.1
unnamed: D2.2 (A), R2.1
PWR_SWITCH_OC: U1.10 (P0.30/AIN6); also elsewhere on the board
SPI_CS: U1.16 (AIN3/P0.05); also elsewhere on the board
SPI_MISO: U1.15 (AIN2/P0.04); also elsewhere on the board
SPI_MOSI: U1.14 (AIN1/P0.03); also elsewhere on the board
SPI_SCLK: U1.17 (P0.06); also elsewhere on the board
TWI_SCL: U1.6 (P0.26); also elsewhere on the board
TWI_SDA: U1.5 (P0.25); also elsewhere on the board
UART_CTS: U1.27 (P0.12); also elsewhere on the board
UART_RTS: U1.26 (P0.11); also elsewhere on the board
UART_RX: U1.23 (P0.08); also elsewhere on the board
UART_TX: U1.20 (P0.07); also elsewhere on the board
UMUX_INH: U1.7 (P0.27); also elsewhere on the board
UMUX_SEL0: U1.1 (P0.21/nRESET); also elsewhere on the board

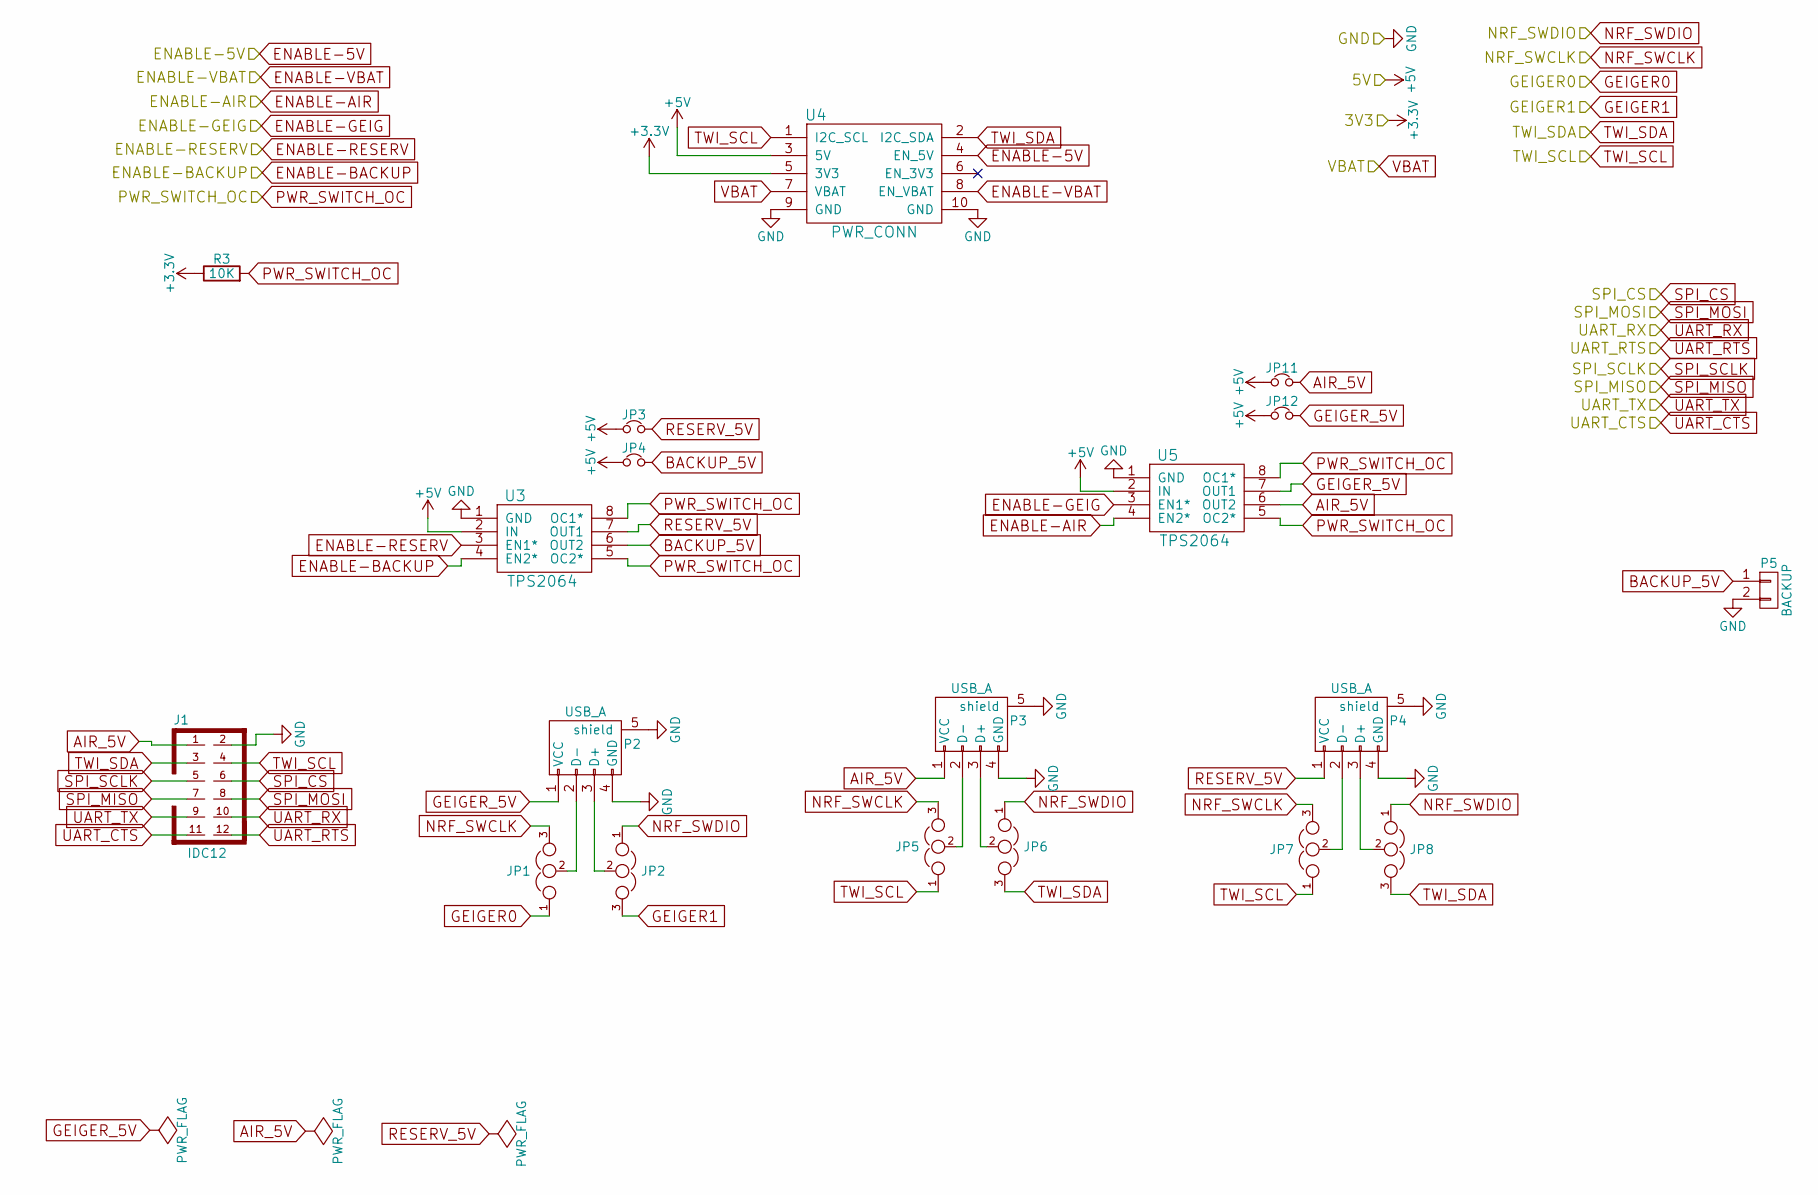
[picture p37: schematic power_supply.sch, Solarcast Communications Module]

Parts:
J1: IDC12; IDC12_connector
JP1, JP2, JP5, JP6, JP7, JP8: JUMPER3; Socket_Strip_Straight_1x03_Pitch2.54mm
JP3, JP4, JP11, JP12: Jumper_NC_Small; Socket_Strip_Straight_1x02_Pitch2.54mm
P2, P3, P4: USB_A; USB_A_receptacle
P5: BACKUP; Socket_Strip_Straight_1x02_Pitch2.54mm
R3: 10K; 0603_HandSoldering
U3, U5: TPS2064
U4: PWR_CONN; IDC10_connector

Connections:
+3V3: R3.1, U4.5 (3V3); also elsewhere on the board
+5V: JP3.1, JP4.1, JP11.1, JP12.1, U3.2 (IN), U4.3 (5V), U5.2 (IN); also elsewhere on the board
AIR_5V: J1.1, JP11.2, P3.1 (VCC), U5.6 (OUT2)
BACKUP_5V: JP4.2, P5.1, U3.6 (OUT2)
ENABLE-5V: U4.4 (EN_5V); also elsewhere on the board
ENABLE-AIR: U5.4 (EN2*); also elsewhere on the board
ENABLE-BACKUP: U3.4 (EN2*); also elsewhere on the board
ENABLE-GEIG: U5.3 (EN1*); also elsewhere on the board
ENABLE-RESERV: U3.3 (EN1*); also elsewhere on the board
ENABLE-VBAT: U4.8 (EN_VBAT); also elsewhere on the board
GEIGER0: JP1.1; also elsewhere on the board
GEIGER1: JP2.3; also elsewhere on the board
GEIGER_5V: JP12.2, P2.1 (VCC), U5.7 (OUT1)
NRF_SWCLK: JP1.3, JP5.3, JP7.3; also elsewhere on the board
NRF_SWDIO: JP2.1, JP6.1, JP8.1; also elsewhere on the board
unnamed: JP1.2, P2.2 (D-)
unnamed: JP2.2, P2.3 (D+)
unnamed: JP5.2, P3.2 (D-)
unnamed: JP6.2, P3.3 (D+)
unnamed: JP7.2, P4.2 (D-)
unnamed: JP8.2, P4.3 (D+)
PWR_SWITCH_OC: R3.2, U3.5 (OC2*), U3.8 (OC1*), U5.5 (OC2*), U5.8 (OC1*); also elsewhere on the board
RESERV_5V: JP3.2, P4.1 (VCC), U3.7 (OUT1)
SPI_CS: J1.6; also elsewhere on the board
SPI_MISO: J1.7; also elsewhere on the board
SPI_MOSI: J1.8; also elsewhere on the board
SPI_SCLK: J1.5; also elsewhere on the board
TWI_SCL: J1.4, JP5.1, JP7.1, U4.1 (I2C_SCL); also elsewhere on the board
TWI_SDA: J1.3, JP6.3, JP8.3, U4.2 (I2C_SDA); also elsewhere on the board
UART_CTS: J1.11; also elsewhere on the board
UART_RTS: J1.12; also elsewhere on the board
UART_RX: J1.10; also elsewhere on the board
UART_TX: J1.9; also elsewhere on the board
VBAT: U4.7 (VBAT); also elsewhere on the board

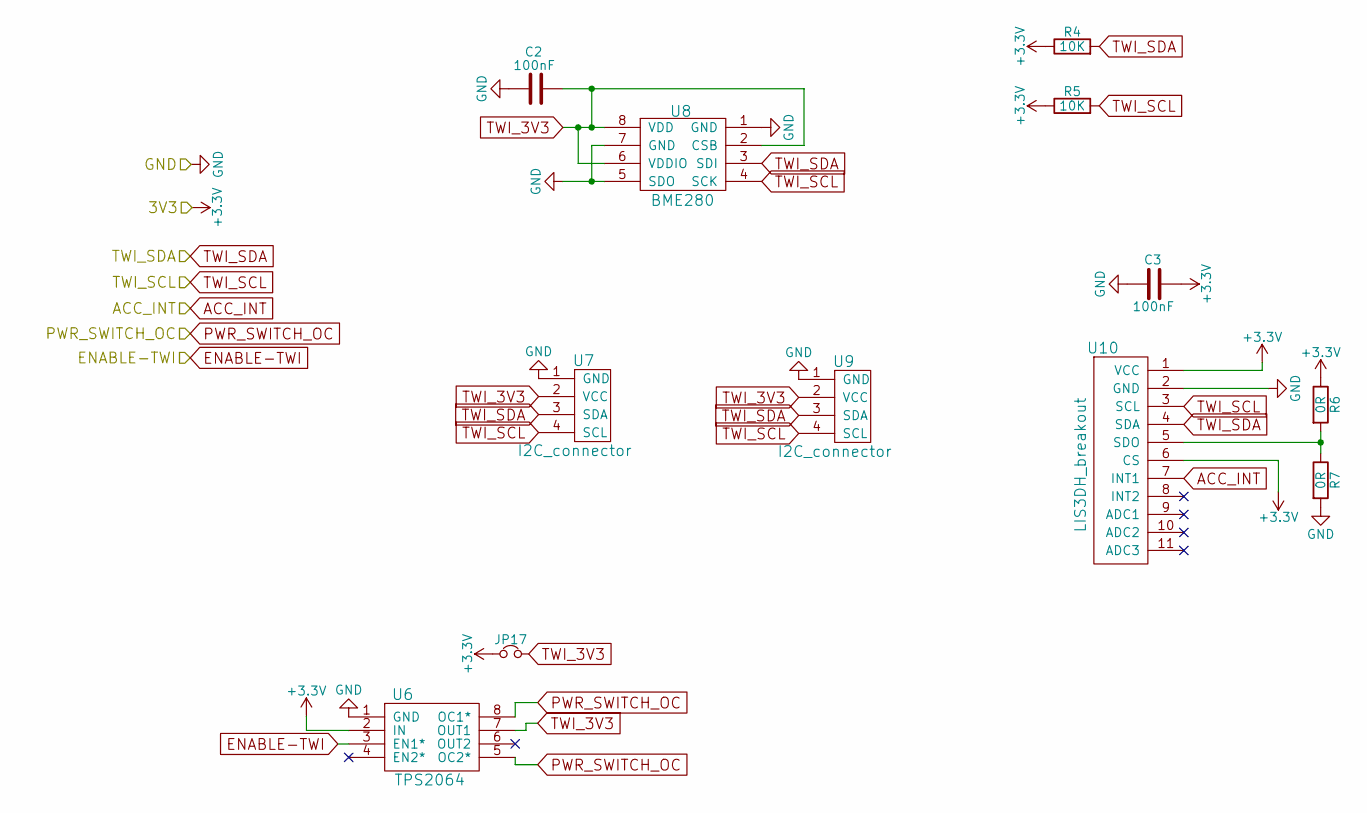
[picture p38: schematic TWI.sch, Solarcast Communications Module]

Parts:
C2, C3: 100nF; 0603_HandSoldering
JP17: Jumper_NC_Small; Socket_Strip_Straight_1x02_Pitch2.54mm
R4, R5: 10K; 0603_HandSoldering
R6, R7: 0R; 0603_HandSoldering
U6: TPS2064
U7, U9: I2C_connector; DIP_Grove_4P-2_0
U8: BME280
U10: LIS3DH_breakout; LIS3DH_breakout_vertical

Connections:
+3V3: C3.2, JP17.1, R4.1, R5.1, R6.1, U6.2 (IN), U10.1 (VCC), U10.6 (CS); also elsewhere on the board
ACC_INT: U10.7 (INT1); also elsewhere on the board
ENABLE-TWI: U6.3 (EN1*); also elsewhere on the board
unnamed: R6.2, R7.1, U10.5 (SDO)
PWR_SWITCH_OC: U6.5 (OC2*), U6.8 (OC1*); also elsewhere on the board
TWI_3V3: C2.2, JP17.2, U6.7 (OUT1), U7.2 (VCC), U8.2 (CSB), U8.6 (VDDIO), U8.8 (VDD), U9.2 (VCC)
TWI_SCL: R5.2, U7.4 (SCL), U8.4 (SCK), U9.4 (SCL), U10.3 (SCL); also elsewhere on the board
TWI_SDA: R4.2, U7.3 (SDA), U8.3 (SDI), U9.3 (SDA), U10.4 (SDA); also elsewhere on the board

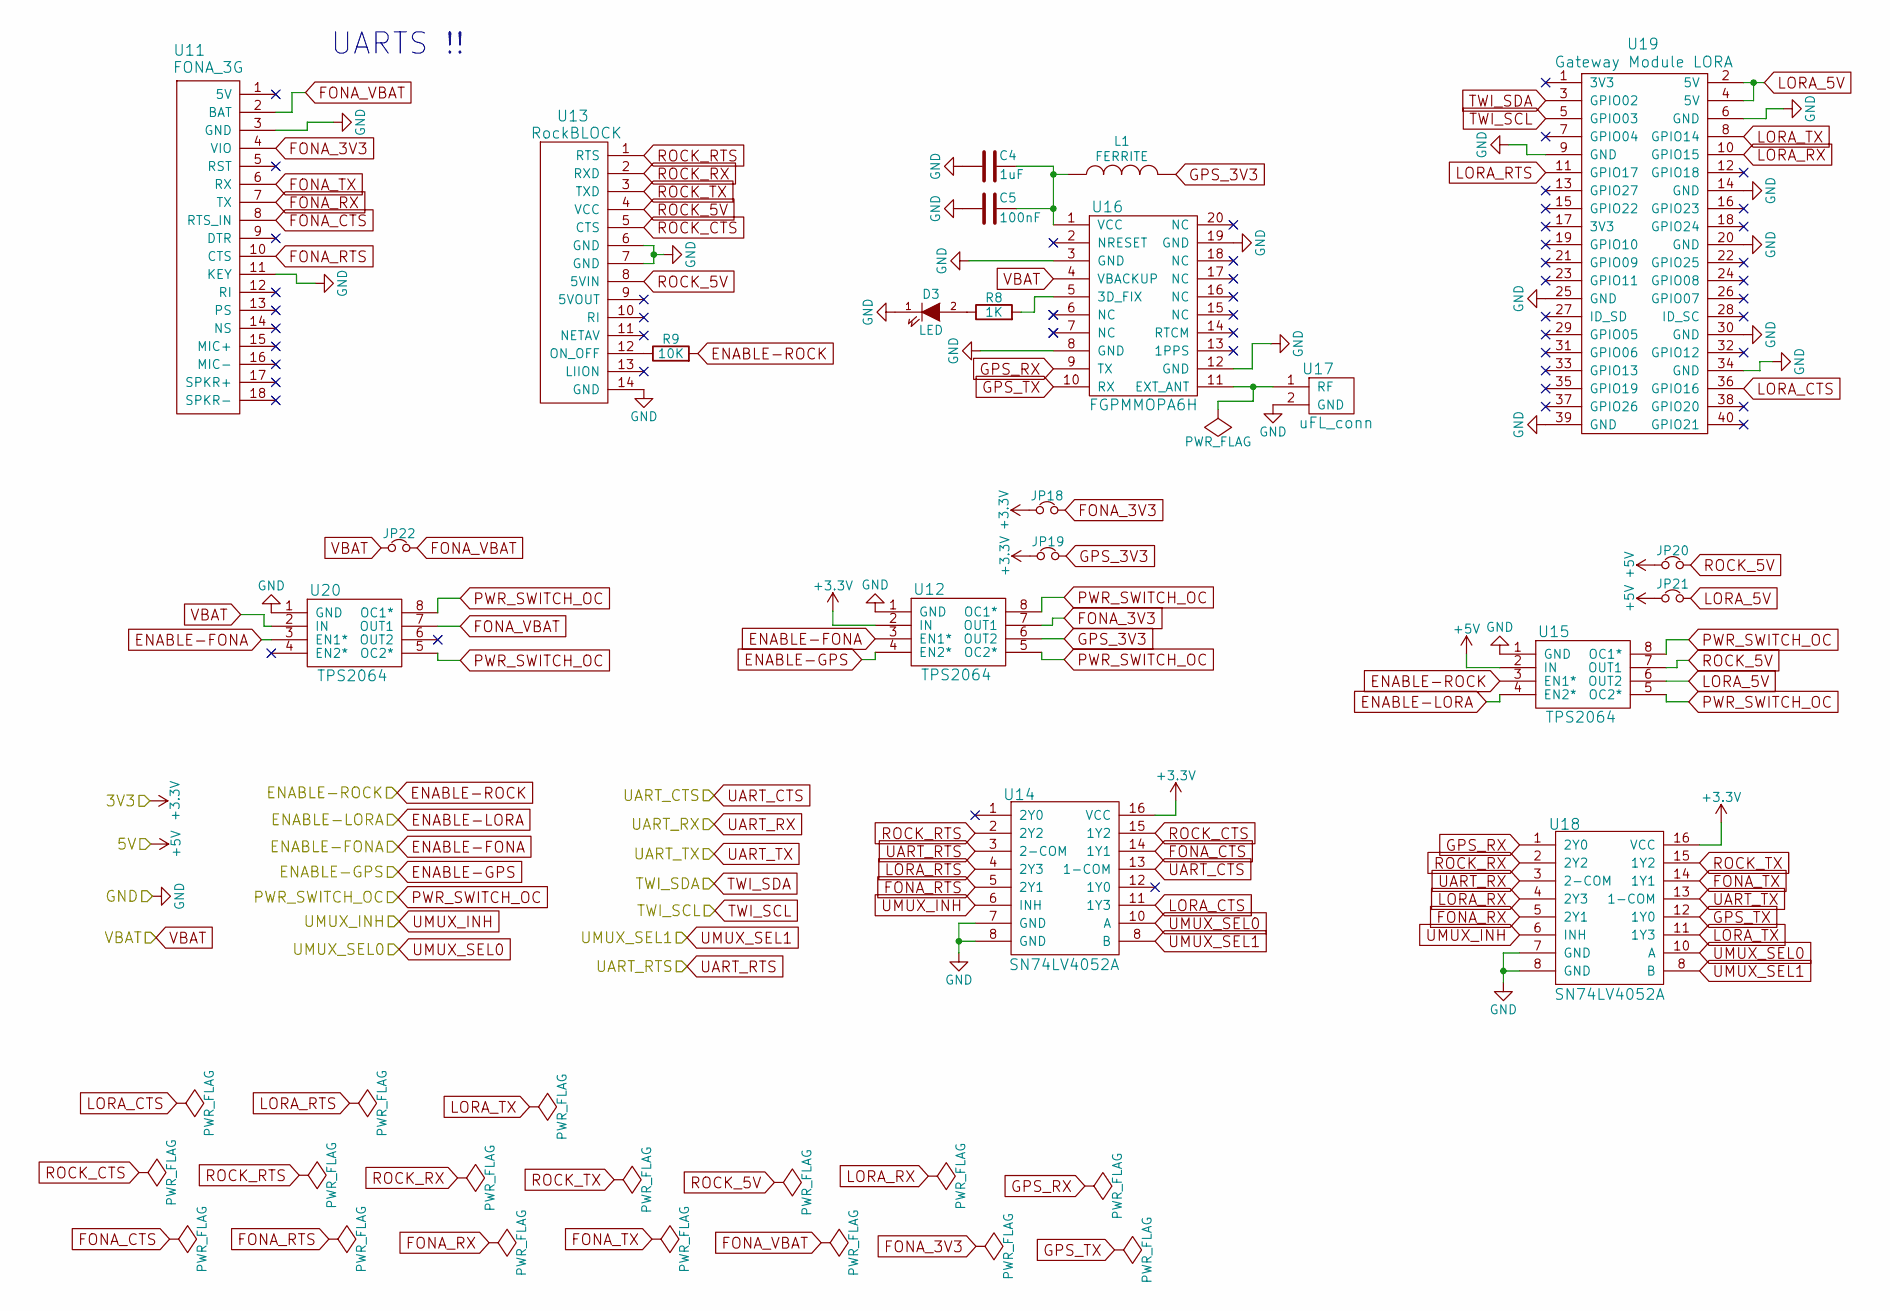
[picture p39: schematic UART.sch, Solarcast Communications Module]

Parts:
C4: 1uF; 0603_HandSoldering
C5: 100nF; 0603_HandSoldering
D3: LED; LED_0603_HandSoldering
JP18, JP19, JP20, JP21, JP22: Jumper_NC_Small; Socket_Strip_Straight_1x02_Pitch2.54mm
L1: FERRITE; 0603_HandSoldering
R8: 1K; 0603_HandSoldering
R9: 10K; 0603_HandSoldering
U11: FONA_3G; FONA_3G_vertical
U12, U15, U20: TPS2064
U13: RockBLOCK; RockBlock_vertical
U14, U18: SN74LV4052A
U16: FGPMMOPA6H; FGPMMOPA6H_GPS
U17: uFL_conn; U.FL-R-SMT
U19: Gateway Module LORA; Solarcast_Gateway_Module

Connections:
+3V3: JP18.1, JP19.1, U12.2 (IN), U14.16 (VCC), U18.16 (VCC); also elsewhere on the board
+5V: JP20.1, JP21.1, U15.2 (IN); also elsewhere on the board
ENABLE-FONA: U12.3 (EN1*), U20.3 (EN1*); also elsewhere on the board
ENABLE-GPS: U12.4 (EN2*); also elsewhere on the board
ENABLE-LORA: U15.4 (EN2*); also elsewhere on the board
ENABLE-ROCK: R9.2, U15.3 (EN1*); also elsewhere on the board
FONA_3V3: JP18.2, U11.4 (VIO), U12.7 (OUT1)
FONA_CTS: U11.8 (RTS_IN), U14.14 (1Y1)
FONA_RTS: U11.10 (CTS), U14.5 (2Y1)
FONA_RX: U11.7 (TX), U18.5 (2Y1)
FONA_TX: U11.6 (RX), U18.14 (1Y1)
FONA_VBAT: JP22.2, U11.2 (BAT), U20.7 (OUT1)
GPS_3V3: JP19.2, L1.2, U12.6 (OUT2)
GPS_RX: U16.9 (TX), U18.1 (2Y0)
GPS_TX: U16.10 (RX), U18.12 (1Y0)
LORA_5V: JP21.2, U15.6 (OUT2), U19.2 (5V), U19.4 (5V)
LORA_CTS: U14.11 (1Y3), U19.36 (GPIO16)
LORA_RTS: U14.4 (2Y3), U19.11 (GPIO17)
LORA_RX: U18.4 (2Y3), U19.10 (GPIO15)
LORA_TX: U18.11 (1Y3), U19.8 (GPIO14)
unnamed: C4.2, C5.2, L1.1, U16.1 (VCC)
unnamed: D3.2 (A), R8.1
unnamed: R8.2, U16.5 (3D_FIX)
unnamed: R9.1, U13.12 (ON_OFF)
unnamed: U16.11 (EXT_ANT), U17.1 (RF)
PWR_SWITCH_OC: U12.5 (OC2*), U12.8 (OC1*), U15.5 (OC2*), U15.8 (OC1*), U20.5 (OC2*), U20.8 (OC1*); also elsewhere on the board
ROCK_5V: JP20.2, U13.4 (VCC), U13.8 (5VIN), U15.7 (OUT1)
ROCK_CTS: U13.5 (CTS), U14.15 (1Y2)
ROCK_RTS: U13.1 (RTS), U14.2 (2Y2)
ROCK_RX: U13.2 (RXD), U18.2 (2Y2)
ROCK_TX: U13.3 (TXD), U18.15 (1Y2)
TWI_SCL: U19.5 (GPIO03); also elsewhere on the board
TWI_SDA: U19.3 (GPIO02); also elsewhere on the board
UART_CTS: U14.13 (1-COM); also elsewhere on the board
UART_RTS: U14.3 (2-COM); also elsewhere on the board
UART_RX: U18.3 (2-COM); also elsewhere on the board
UART_TX: U18.13 (1-COM); also elsewhere on the board
UMUX_INH: U14.6 (INH), U18.6 (INH); also elsewhere on the board
UMUX_SEL0: U14.10 (A), U18.10 (A); also elsewhere on the board
VBAT: JP22.1, U16.4 (VBACKUP), U20.2 (IN); also elsewhere on the board

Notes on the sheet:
UARTS !!

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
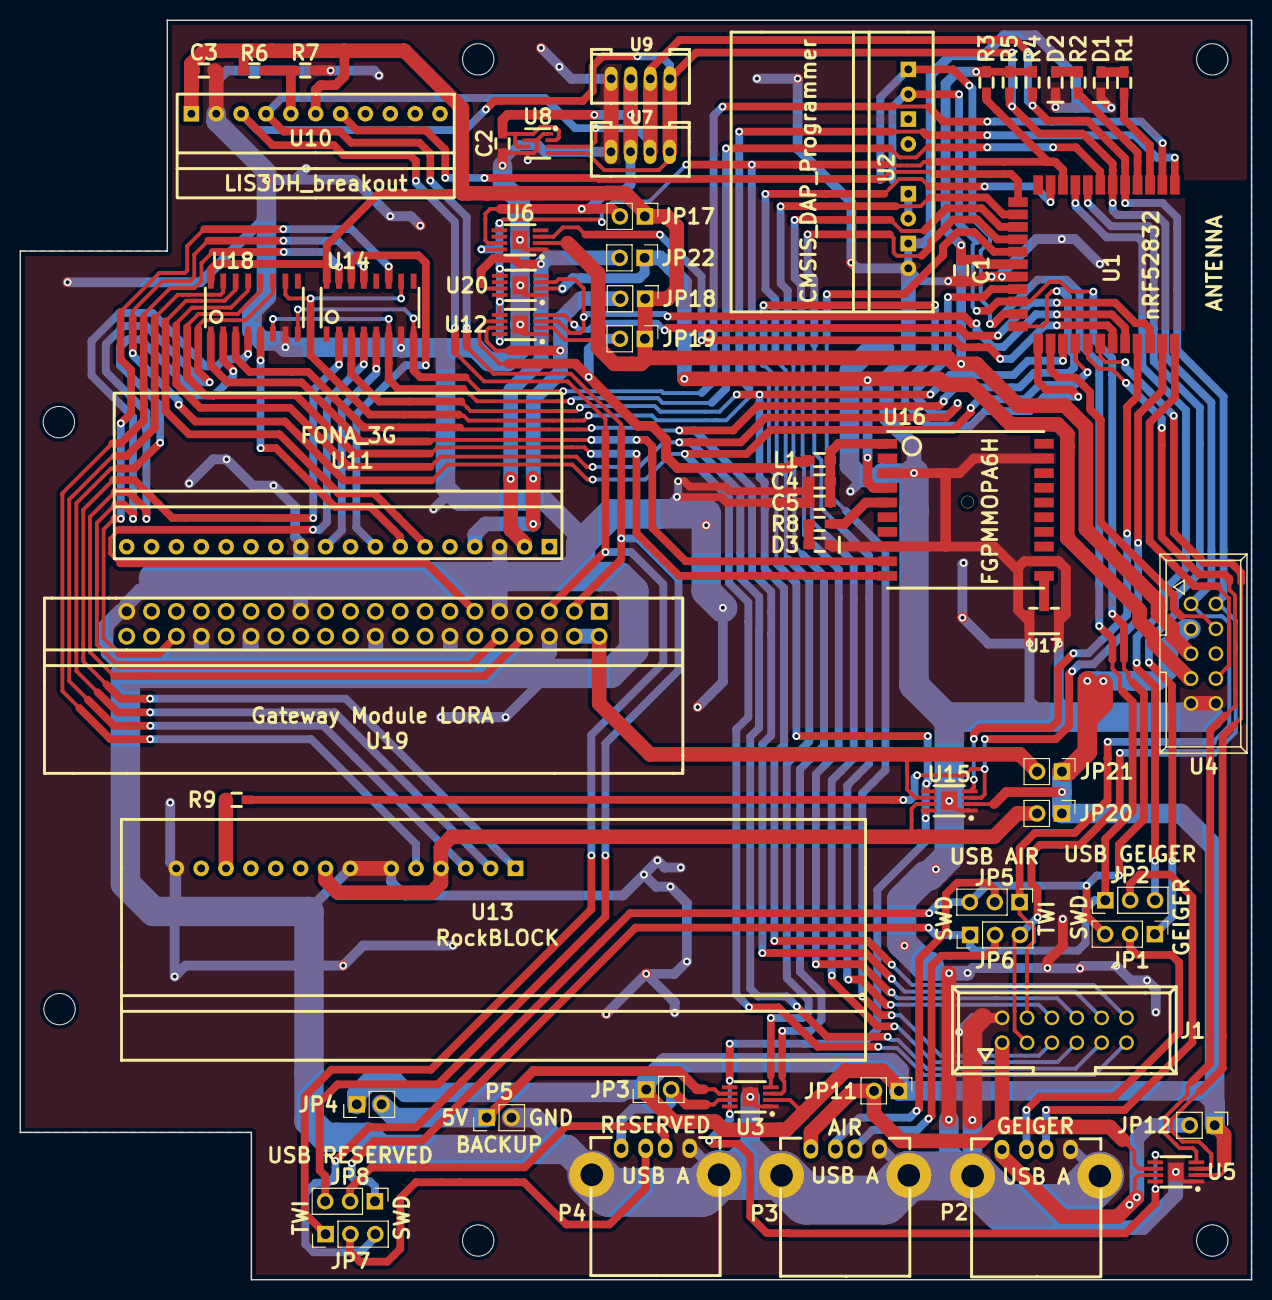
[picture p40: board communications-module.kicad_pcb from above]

Board: 2 copper layers, 125.8 x 128.6 mm, 59 parts (0 on the bottom side), 74 nets.

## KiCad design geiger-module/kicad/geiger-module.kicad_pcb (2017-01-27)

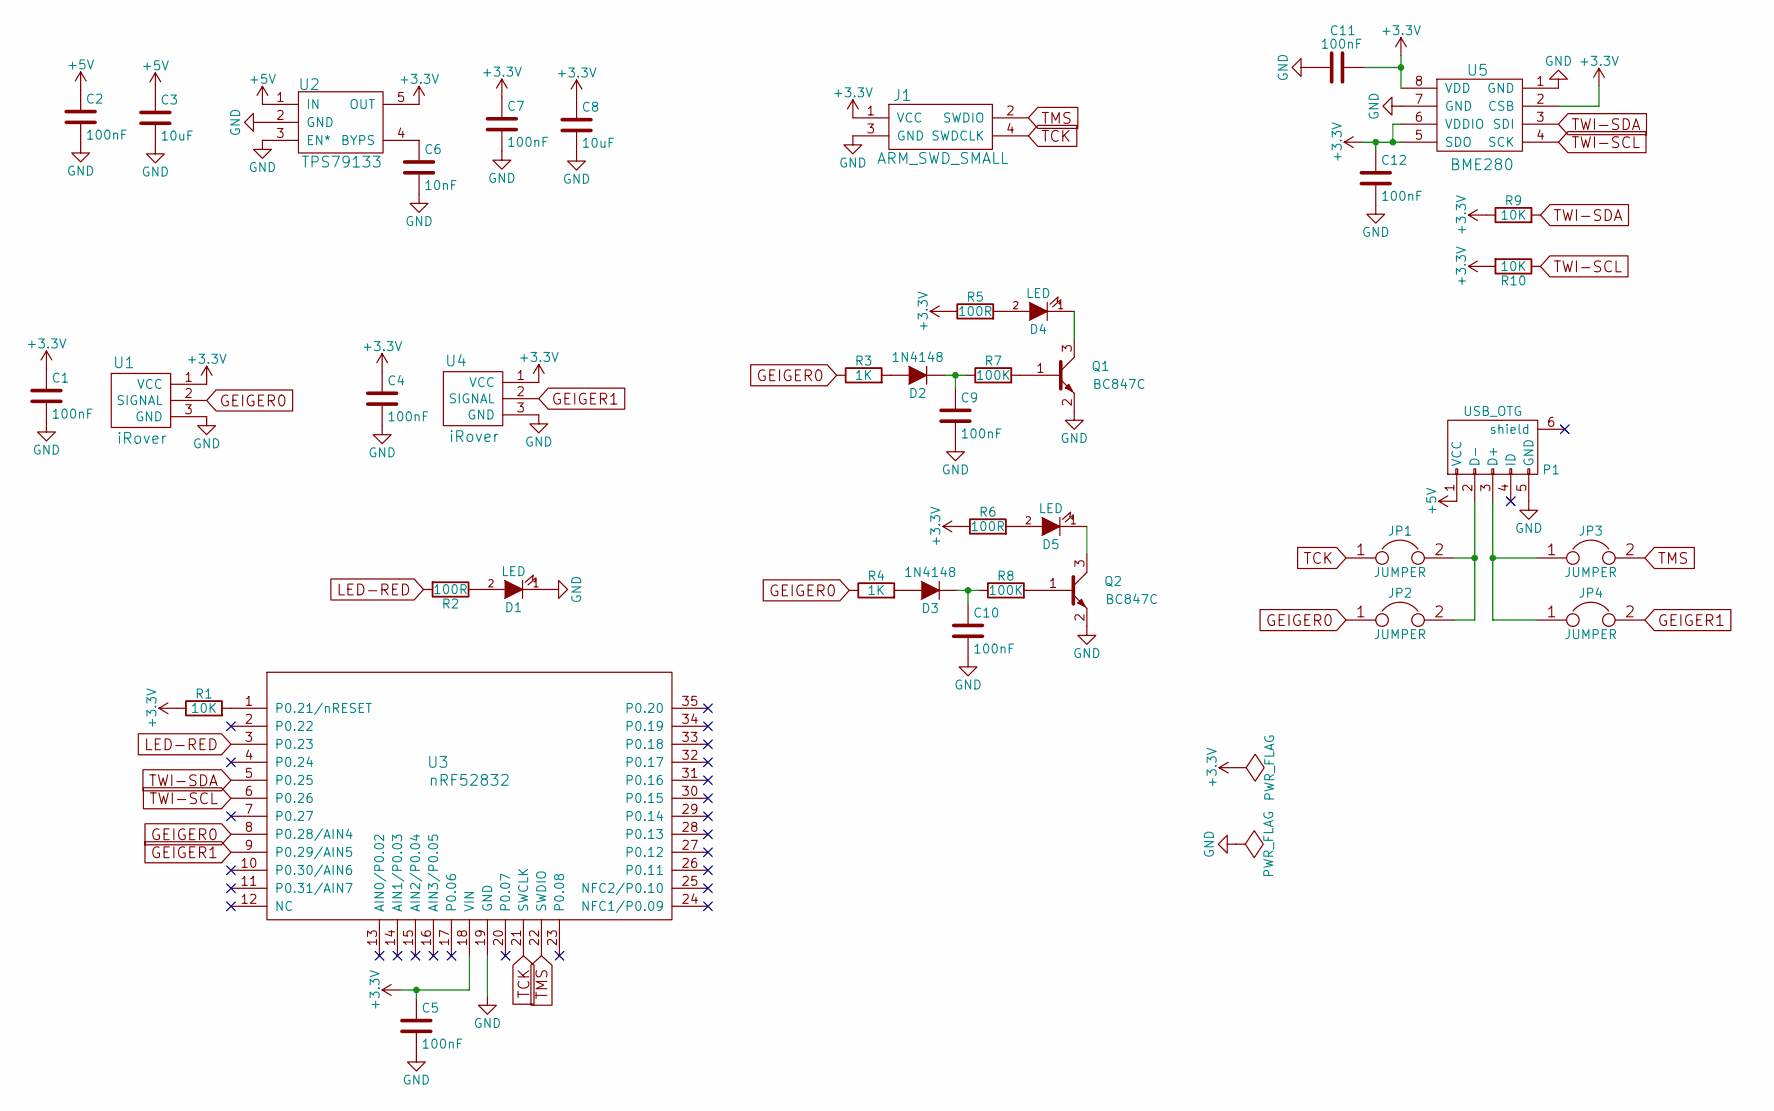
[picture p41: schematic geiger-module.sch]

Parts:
C1, C2, C4, C5, C7, C9, C10, C11, C12: 100nF; 0603_HandSoldering
C3, C8: 10uF; 0603_HandSoldering
C6: 10nF; 0603_HandSoldering
D1, D4, D5: LED; LED_0603_HandSoldering
D2, D3: 1N4148; SOD-323
J1: ARM_SWD_SMALL; Socket_Strip_Straight_2x02
JP1, JP2, JP3, JP4: JUMPER; Socket_Strip_Straight_1x02
P1: USB_OTG; DCP-USBCB-SC
Q1, Q2: BC847C; SOT-23
R1, R9, R10: 10K; 0603_HandSoldering
R2, R5, R6: 100R; 0603_HandSoldering
R3, R4: 1K; 0603_HandSoldering
R7, R8: 100K; 0603_HandSoldering
U1, U4: iRover; B3B-PH-SM4-TB_IROVER_CONNECTOR
U2: TPS79133
U3: nRF52832; nRF52832-SMD
U5: BME280

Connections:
+3V3: C1.1, C4.1, C5.1, C7.1, C8.1, C11.1, C12.1, J1.1 (VCC), R1.1, R5.1, R6.1, R9.1, R10.2, U1.1 (VCC), U2.5 (OUT), U3.18 (VIN), U4.1 (VCC), U5.2 (CSB), U5.5 (SDO), U5.6 (VDDIO), U5.8 (VDD)
+5V: C2.1, C3.1, P1.1 (VCC), U2.1 (IN)
GEIGER0: JP2.1, R3.1, R4.1, U1.2 (SIGNAL), U3.8 (P0.28/AIN4)
GEIGER1: JP4.2, U3.9 (P0.29/AIN5), U4.2 (SIGNAL)
GND: C1.2, C2.2, C3.2, C4.2, C5.2, C6.2, C7.2, C8.2, C9.2, C10.2, C11.2, C12.2, D1.1 (K), J1.3 (GND), P1.5 (GND), Q1.2 (E), Q2.2 (E), U1.3 (GND), U2.2 (GND), U2.3 (EN*), U3.19 (GND), U4.3 (GND), U5.1 (GND), U5.7 (GND)
LED-RED: R2.2, U3.3 (P0.23)
unnamed: C6.1, U2.4 (BYPS)
unnamed: C9.1, D2.1 (K), R7.1
unnamed: C10.1, D3.1 (K), R8.1
unnamed: D1.2 (A), R2.1
unnamed: D2.2 (A), R3.2
unnamed: D3.2 (A), R4.2
unnamed: D4.1 (K), Q1.3 (C)
unnamed: D4.2 (A), R5.2
unnamed: D5.1 (K), Q2.3 (C)
unnamed: D5.2 (A), R6.2
unnamed: JP1.2, JP2.2, P1.2 (D-)
unnamed: JP3.1, JP4.1, P1.3 (D+)
unnamed: Q1.1 (B), R7.2
unnamed: Q2.1 (B), R8.2
unnamed: R1.2, U3.1 (P0.21/nRESET)
TCK: J1.4 (SWDCLK), JP1.1, U3.21 (SWCLK)
TMS: J1.2 (SWDIO), JP3.2, U3.22 (SWDIO)
TWI-SCL: R10.1, U3.6 (P0.26), U5.4 (SCK)
TWI-SDA: R9.2, U3.5 (P0.25), U5.3 (SDI)

Board: 2 copper layers, 40 parts (1 on the bottom side), 25 nets, no tracks yet.

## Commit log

2017-01-11 Basic requirements, work in progress
    [Solarcast-Air-PCB.step, Solarcast-Geiger-PCB.step]
2017-01-13 improved spec for battery
2017-01-13 updates on spec and typos
    [Solarcast-Air-PCB.dxf]
2017-01-14 battery module update
2017-01-14 refined spec for iot battery pack
2017-01-17 connector info
2017-01-19 Added KiCad project
    [Part Studio 1 - Face.dxf, air-module BOM.ods, air-module.csv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]
2017-01-19 Added Geiger Module KiCad project
    [geiger-module.kicad_pcb, geiger-module.sch]
2017-01-19 Updated Geiger Module schematic
    [geiger-module.sch]
2017-01-20 Added Gateway Module KiCad project
    [gateway-module.kicad_pcb, gateway-module.sch]
2017-01-20 Updated Gateway Module schematic
2017-01-24 Air Module PCB update
    [air-module.kicad_pcb, air-module.sch]
2017-01-25 Geiger Module PCB and schematic update
    [geiger-module.sch]
2017-01-27 Schematic and PCB footer update
    [air-module.kicad_pcb, air-module.sch]
2017-01-27 Air Module gerbers update
    [air-module-B_Cu.gbl, air-module-B_Mask.gbs, air-module-B_SilkS.gbo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]
2017-01-30 Air Geiger Modules PCB update
    [air-module.kicad_pcb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]
2017-01-31 Communications Module PCB update
    [communications-module.kicad_pcb, communications-module.sch, gateway-module.sch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]
2017-01-31 Gateway Module PCB update
2017-01-31 Communications Module update
    [communications-module.kicad_pcb, communications-module.sch]
2017-02-02 Fixes #1
    [TWI.sch, UART.sch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]
2017-02-02 Fixes #2
    [air-module.kicad_pcb, geiger-module.sch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]
2017-02-03 Removed INA219
    Removed INA219, current measurement is built into the battery module.
2017-02-03 Updated power spec
    Regulators are now on battery module, not required here anymore.
2017-02-03 All schematics update
    [TWI.sch, UART.sch, communications-module.kicad_pcb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]
2017-02-03 All gerbers update
    [UART.sch, communications-module.kicad_pcb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]
2017-02-03 Communications Module schematic update
    [TWI.sch, UART.sch, communications-module.sch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]
2017-02-06 Communications Module footprints update
    [UART.sch, power_supply.sch]
2017-02-06 Communications Module PCB components placed
    [UART.sch, communications-module.kicad_pcb, communications-module.sch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]
2017-02-06 Communications Module schematic PDF update
2017-02-07 i2c dump of battery module bus and registers
    [IoT-battery-pac-i2c-dump.txt]
2017-02-10 Added Communications Module gerbers
    [communications-module-B_Cu.gbl, communications-module-B_Mask.gbs, communications-module-Edge_Cuts.gko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]
2017-02-10 Communications Module gerbers update
    [UART.sch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]
2017-02-11 Communications Module PCB correction
    [TWI.sch, UART.sch, communications-module.sch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]
2017-02-11 Added PCB correction screenshots
2017-02-11 Mathe the corrected version the latest.
    [TWI.sch, UART.sch, communications-module.sch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]
2017-02-14 Added all BOMs
    [air-module BOM.ods, air-module-BOM.ods, communications-module-BOM.ods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]
2017-02-16 Added supplier links to BOMs
    [air-module-BOM.ods, communications-module-BOM.ods, gateway-module-BOM.ods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]
2017-02-17 Small cleanup
    [gateway-module.csv, geiger-module.csv]
2017-02-24 Fixes #9 #8
    [air-module.kicad_pcb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]
2017-02-24 Added Air and Gateway Module schematics
2017-02-24 Added Plantower adapter PCB
    [plantower-adapter.kicad_pcb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]
2017-02-27 Air Module PCB update, Fixes #4, Fixes #5, Fixes #6, Fixes #7, Fixes #8
    [air-module-BOM.ods, air-module.kicad_pcb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]
2017-03-03 Updated BOM
    [communications-module-BOM.ods, geiger-module-BOM.ods]
2017-05-04 moved IoT battery pack in a standalone repository
    [IoT-battery-pac-i2c-dump.txt]
2017-06-02 air sensor test results
    [raw_data.xlsx]
2017-06-05 test 2 results upload
    [raw_data.xlsx]
2017-06-06 test results
    [raw_data.xlsx]
2017-06-08 test results upload
    [raw_data.xlsx]
2017-06-15 sensor placement graph
2017-08-24 Merged the battery pack to main repository
    [IoT-battery-pac-i2c-dump.txt]
